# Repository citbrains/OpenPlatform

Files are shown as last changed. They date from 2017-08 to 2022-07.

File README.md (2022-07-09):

# OpenPlatform
Open Platform Humanoid Robot  

We are developing an open platform humanoid robot for the RoboCup Humanoid League.  
We aim to develop a robust robot system that helps the experiment on the real robot.  
The original robot was designed by Shimoyoshi.



GankenKun ver.3 (2020/11/22)



### Prizes
2019 RoboCup 4on4 3rd, Technical Challenge 2nd, Drop In Challenge 2nd  
2018 RoboCup 4on4 3rd, Technical Challenge 1st  
2017 RoboCup 4on4 3rd, Technical Challenge 1st  

### VIDEO
https://www.youtube.com/playlist?list=PLB7_jZwkBJdQZTIP_5HFZ_qUzT54mZ3Gq

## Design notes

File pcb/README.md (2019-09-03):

# PCB data

We design the circuit using EAGLE.

## Version 1

`ver1/OP_Robot_garv`: This circuit is the doughterboard for Raspberry Pi.  
For preview, see `OPR_Main_v2_board.pdf` and `OPR_Main_v2_schematics.pdf`.  

## Version 3

`ver3/power_circuit`: This circuit is the power supply switching circuit.  

## Bugs

If you find a bug please let me know by opening an issue.

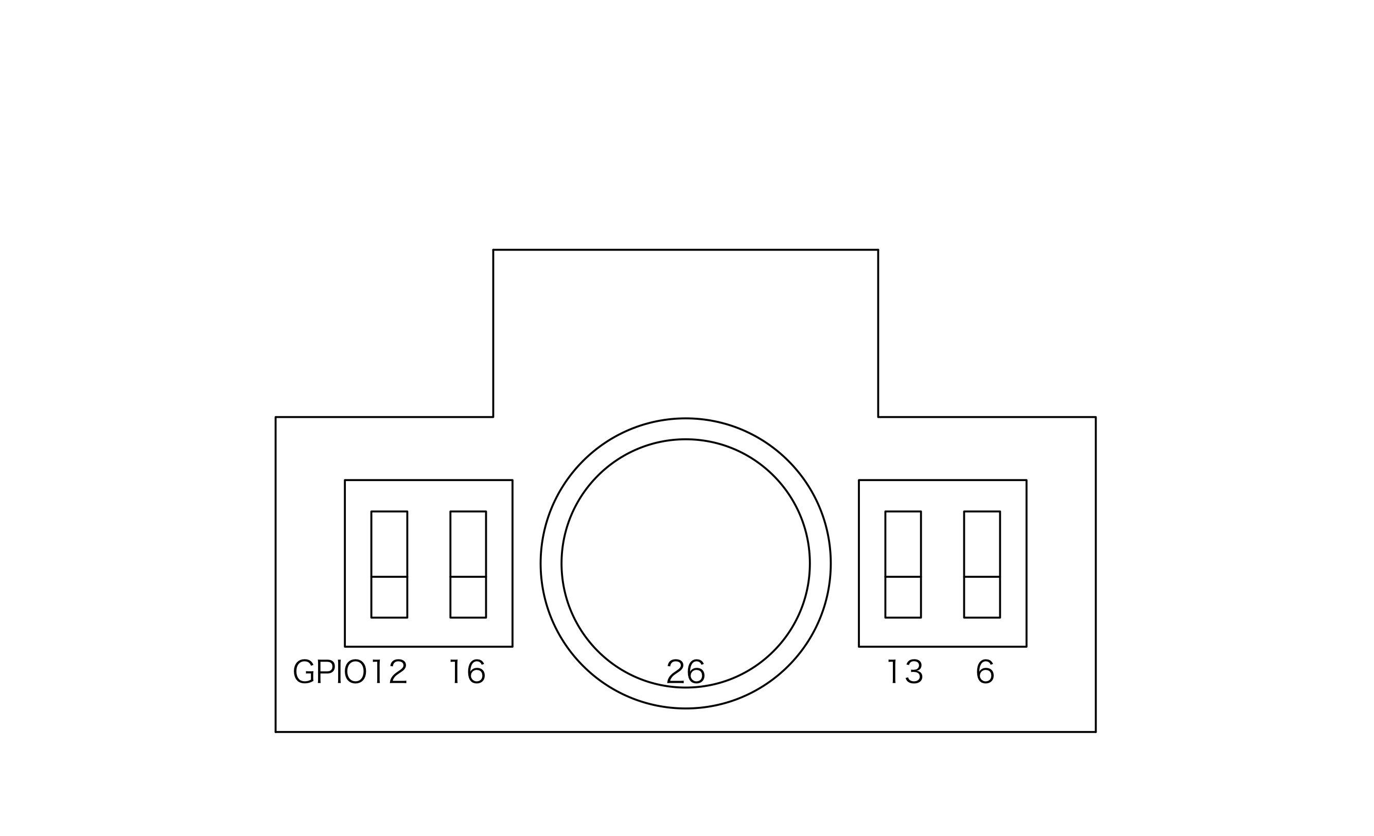
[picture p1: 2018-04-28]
mechanism/OPR_SW_assain.png

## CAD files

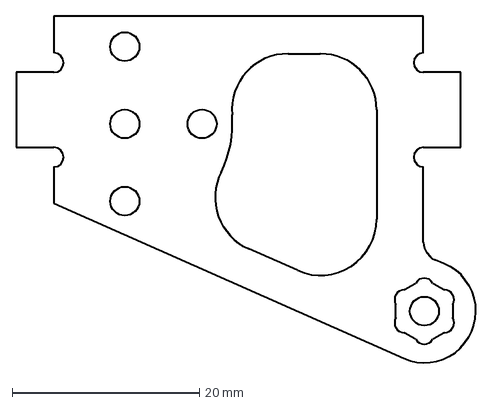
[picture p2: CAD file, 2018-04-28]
mechanism/OpenPlatform_ver3_0/dxf/A2017/2mm/付け根_サブフレーム_6_1.dxf
49.3 x 37.3 mm

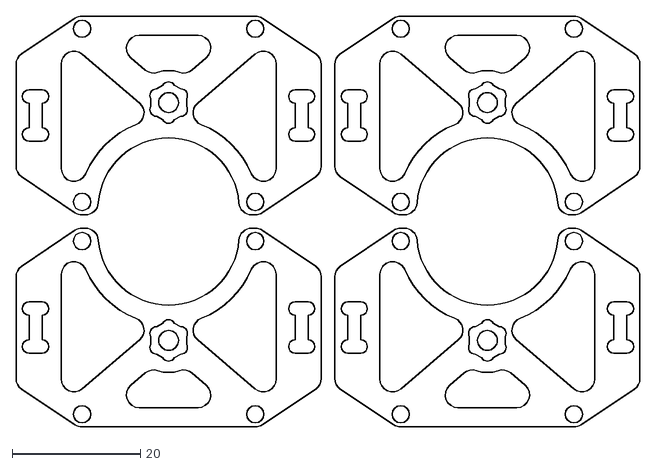
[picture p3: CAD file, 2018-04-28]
mechanism/OpenPlatform_ver3_0/dxf/A2017/3mm/付け根_メインフレーム_6_1.dxf
97.3 x 64.1

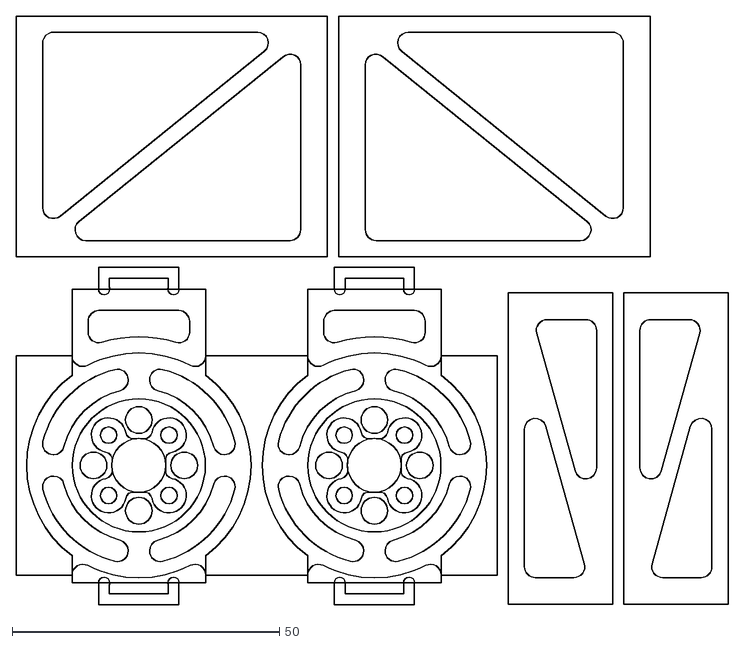
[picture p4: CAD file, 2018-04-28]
mechanism/OpenPlatform_ver3_0/dxf/A2017/5mm/付け根ロール_メインフレーム_6_1.dxf
133.3 x 110.2

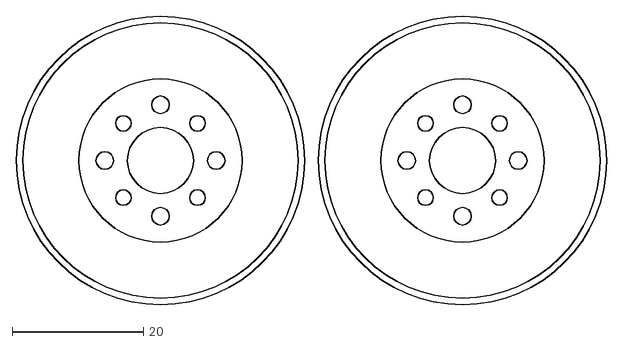
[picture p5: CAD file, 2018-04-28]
mechanism/OpenPlatform_ver3_0/dxf/A2017/付け根ロール_サブフレーム_6_4.dxf
90.1 x 44.0

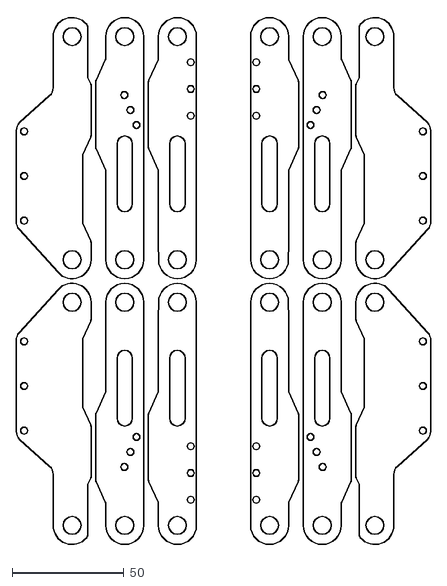
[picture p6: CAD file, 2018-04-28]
mechanism/OpenPlatform_ver3_0/dxf/GFRP/2mm/長穴減速_ホーン_1_2.dxf
185.7 x 237.5

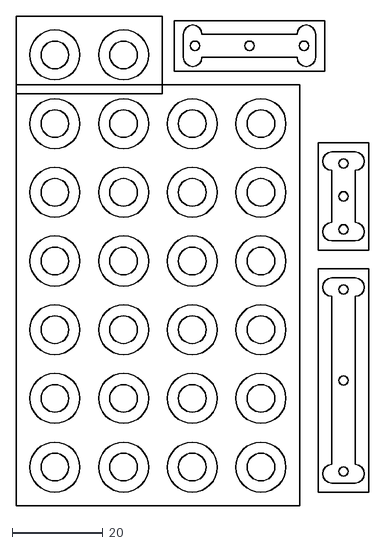
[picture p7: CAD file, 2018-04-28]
mechanism/OpenPlatform_ver3_0/dxf/POM/8mm/スペーサ.dxf
77.5 x 107.6

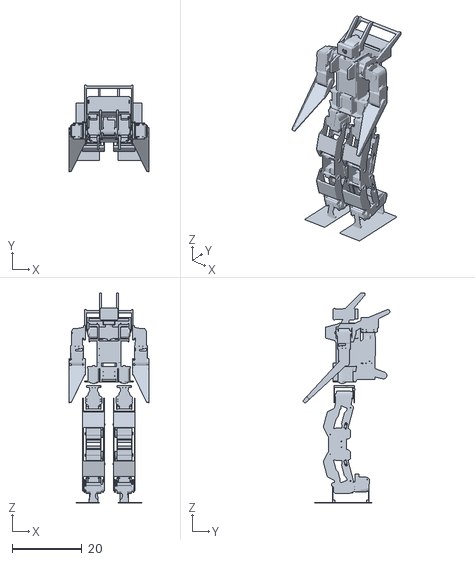
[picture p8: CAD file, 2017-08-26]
vrep/OpenPlatform_ver1_0_Sim.stl
23.0 x 24.9 x 60.2

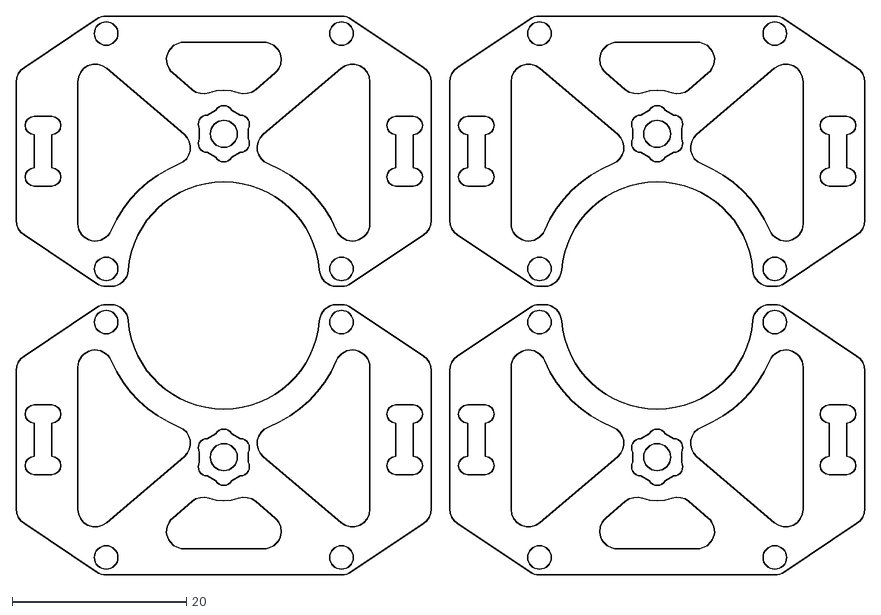
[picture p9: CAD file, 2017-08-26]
vrep/OpenPlatform_ver1_0_Sim/dxf/A2017/3mm/付け根_メインフレーム_6_1.dxf
97.3 x 64.1

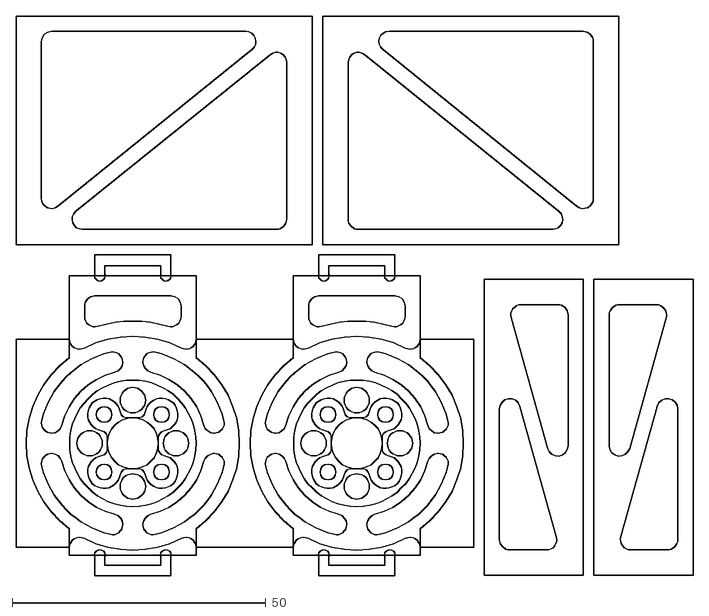
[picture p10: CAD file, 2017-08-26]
vrep/OpenPlatform_ver1_0_Sim/dxf/A2017/5mm/付け根ロール_メインフレーム_6_1.dxf
133.3 x 110.2

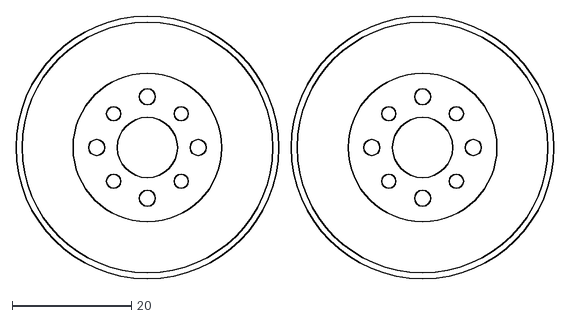
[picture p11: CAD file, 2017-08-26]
vrep/OpenPlatform_ver1_0_Sim/dxf/A2017/付け根ロール_サブフレーム_6_4.dxf
90.1 x 44.0

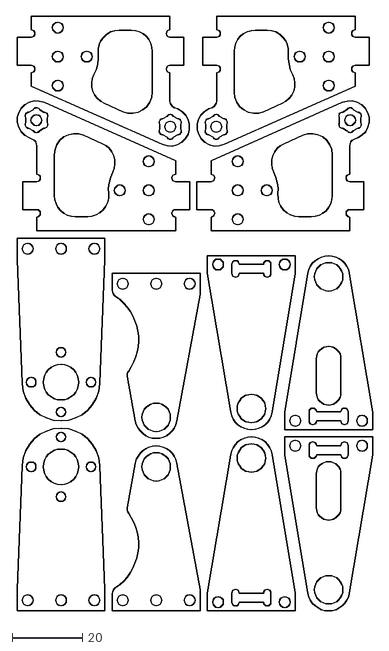
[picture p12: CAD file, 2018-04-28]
mechanism/OpenPlatform_ver3_0/dxf/A2017/2mm/足裏_メインフレーム_1_1.dxf
101.4 x 169.3

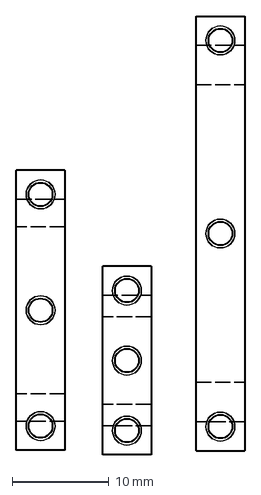
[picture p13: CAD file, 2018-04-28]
mechanism/OpenPlatform_ver3_0/dxf/POM/8mm/リンク_ふくらはぎ_サブフレーム_1_2(予備案).dxf
23.6 x 45.4 mm

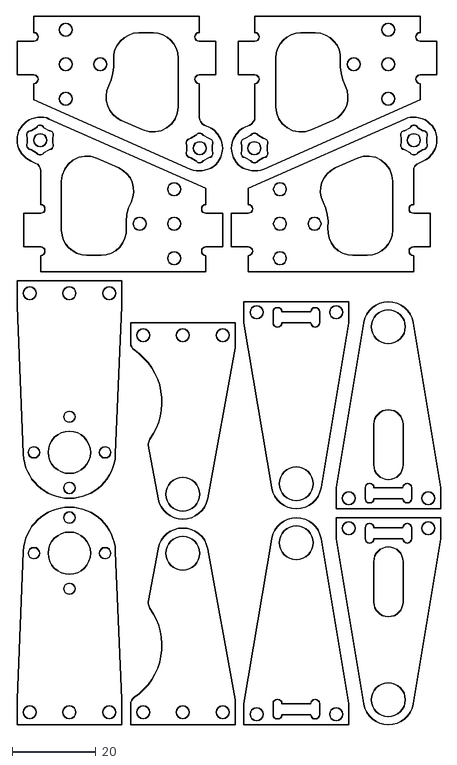
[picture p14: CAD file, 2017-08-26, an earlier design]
vrep/OpenPlatform_ver1_0_Sim/dxf/A2017/2mm/足裏_メインフレーム_1_1.dxf
101.4 x 169.3

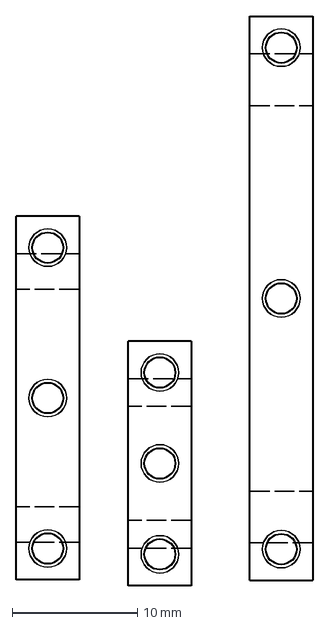
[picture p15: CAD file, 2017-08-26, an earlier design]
vrep/OpenPlatform_ver1_0_Sim/dxf/POM/8mm/リンク_ふくらはぎ_サブフレーム_1_2(予備案).dxf
23.6 x 45.4 mm

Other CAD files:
mechanism/OpenPlatform_ver3_0/dxf/GFRP/2mm/長穴減速_ホーン_1_2(1).dxf
vrep/OpenPlatform_ver1_0_Sim/dxf/POM/8mm/スペーサ.dxf
mechanism/OpenPlatform_ver1_0/上半身.iam
mechanism/OpenPlatform_ver1_0/上半身/コックピット/コックピット_2/コックピット_2.iam
mechanism/OpenPlatform_ver1_0/上半身/コックピット/コックピット_2/コックピット_2_サブフレーム_1.ipt
mechanism/OpenPlatform_ver1_0/上半身/コックピット/コックピット_2/コックピット_2_サブフレーム_2.ipt
mechanism/OpenPlatform_ver1_0/上半身/コックピット/コックピット_2/コックピット_2_サブフレーム_3.ipt
mechanism/OpenPlatform_ver1_0/上半身/コックピット/コックピット_2/コックピット_2_サブフレーム_4.ipt
mechanism/OpenPlatform_ver1_0/上半身/コックピット/コックピット_2/コックピット_2_サブフレーム_5.ipt
mechanism/OpenPlatform_ver1_0/上半身/コックピット/コックピット_2/コックピット_2_サブフレーム_6.ipt
mechanism/OpenPlatform_ver1_0/上半身/コックピット/コックピット_2/コックピット_2_メインフレーム_1.ipt
mechanism/OpenPlatform_ver1_0/上半身/コックピット/コックピット_2/コックピット_2_メインフレーム_1_MIR.ipt
mechanism/OpenPlatform_ver1_0/上半身/コックピット/コックピット_2/コックピット_2_メインフレーム_2.ipt
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

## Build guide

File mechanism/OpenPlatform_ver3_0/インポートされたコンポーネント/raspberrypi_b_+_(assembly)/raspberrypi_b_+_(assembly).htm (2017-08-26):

Autodesk Inventor 変換レポート | 2016年5月3日 ( 18:08)

ソース ファイル: | C:\Users\hiroaki\Documents\kenkyuu\二足\二足ver3.0\既製品\raspberry-pi-model-b-2.snapshot.15\raspberrypi_b_+_(assembly).SLDASM
トランスレータのタイプ: | SolidWorks | 送信システム: | SolidWorks 2013
作成者: | | 変換時間: | 00:00:23

オプション
インポートのタイプ: | N/A
インポートするエンティティ タイプ: | ソリッド, サーフェス, ワイヤ
修復環境に読み込む: | はい
アセンブリを単一パーツとしてインポート: | いいえ
次のサーフェスを作成: | 単一コンポジット フィーチャ
単位: | ミリメートル
ロード時にパーツを確認: | いいえ
自動ステッチ: | いいえ
高度なヒーリングを有効化: | N/A

## コンポーネント

次の表は、Inventor 内に作成されたパーツとアセンブリの一覧です:

+/- | 名前 | Inventor ファイル | ステータス
[ ] | raspberrypi_b_+_(assembly).iam | C:\Users\hiroaki\Documents\kenkyuu\二足\インポートされたコンポーネント\raspberrypi_b_+_(assembly)\raspberrypi_b_+_(assembly).iam | 成功
[ ] | raspberry_pi_B+_(bar_180_2x20).ipt | C:\Users\hiroaki\Documents\kenkyuu\二足\インポートされたコンポーネント\raspberrypi_b_+_(assembly)\raspberry_pi_B+_(bar_180_2x20).ipt | 成功
[ ] | raspberry_pi_B+_(QFN64).ipt | C:\Users\hiroaki\Documents\kenkyuu\二足\インポートされたコンポーネント\raspberrypi_b_+_(assembly)\raspberry_pi_B+_(QFN64).ipt | 成功
[+] [-] | raspberry_pi_B+_(168_FBGA_12x12).ipt | C:\Users\hiroaki\Documents\kenkyuu\二足\インポートされたコンポーネント\raspberrypi_b_+_(assembly)\raspberry_pi_B+_(168_FBGA_12x12).ipt | Warning

厳密度 | エンティティ ID | メッセージ
Warning | 25905 | 一部のサーフェスが簡略化されました
[ ] | raspberry_pi_B+_(micro_USB).iam | C:\Users\hiroaki\Documents\kenkyuu\二足\インポートされたコンポーネント\raspberrypi_b_+_(assembly)\raspberry_pi_B+_(micro_USB).iam | 成功
[ ] | raspberry_pi_B+_(micro_USB_cover).ipt | C:\Users\hiroaki\Documents\kenkyuu\二足\インポートされたコンポーネント\raspberrypi_b_+_(assembly)\raspberry_pi_B+_(micro_USB_cover).ipt | 成功
[ ] | raspberry_pi_B+_(micro_USB_contacts).ipt | C:\Users\hiroaki\Documents\kenkyuu\二足\インポートされたコンポーネント\raspberrypi_b_+_(assembly)\raspberry_pi_B+_(micro_USB_contacts).ipt | 成功
[ ] | raspberry_pi_B+_(HDMI_socket).iam | C:\Users\hiroaki\Documents\kenkyuu\二足\インポートされたコンポーネント\raspberrypi_b_+_(assembly)\raspberry_pi_B+_(HDMI_socket).iam | 成功
[ ] | raspberry_pi__HDMI_socket_cover.ipt | C:\Users\hiroaki\Documents\kenkyuu\二足\インポートされたコンポーネント\raspberrypi_b_+_(assembly)\raspberry_pi__HDMI_socket_cover.ipt | 成功
[ ] | raspberry_pi__HDMI_socket_inside.ipt | C:\Users\hiroaki\Documents\kenkyuu\二足\インポートされたコンポーネント\raspberrypi_b_+_(assembly)\raspberry_pi__HDMI_socket_inside.ipt | 成功
[ ] | raspberry_pi__HDMI_socket_large_pin.ipt | C:\Users\hiroaki\Documents\kenkyuu\二足\インポートされたコンポーネント\raspberrypi_b_+_(assembly)\raspberry_pi__HDMI_socket_large_pin.ipt | 成功
[ ] | raspberry_pi__HDMI_socket_small_pin.ipt | C:\Users\hiroaki\Documents\kenkyuu\二足\インポートされたコンポーネント\raspberrypi_b_+_(assembly)\raspberry_pi__HDMI_socket_small_pin.ipt | 成功
[+] [-] | raspberry_pi_B+_(RJ45).ipt | C:\Users\hiroaki\Documents\kenkyuu\二足\インポートされたコンポーネント\raspberrypi_b_+_(assembly)\raspberry_pi_B+_(RJ45).ipt | Warning

厳密度 | エンティティ ID | メッセージ
Warning | 114479 | 一部のサーフェスが簡略化されました
[ ] | raspberry_pi_B+_(15_pin_FFC_Connector).iam | C:\Users\hiroaki\Documents\kenkyuu\二足\インポートされたコンポーネント\raspberrypi_b_+_(assembly)\raspberry_pi_B+_(15_pin_FFC_Connector).iam | 成功
[ ] | raspberry_pi__15_pin_FFC_Connector_body.ipt | C:\Users\hiroaki\Documents\kenkyuu\二足\インポートされたコンポーネント\raspberrypi_b_+_(assembly)\raspberry_pi__15_pin_FFC_Connector_body.ipt | 成功
[ ] | raspberry_pi__15_pin_FFC_Connector_locker.ipt | C:\Users\hiroaki\Documents\kenkyuu\二足\インポートされたコンポーネント\raspberrypi_b_+_(assembly)\raspberry_pi__15_pin_FFC_Connector_locker.ipt | 成功
[ ] | raspberry_pi__15_pin_FFC_Connector_pins.ipt | C:\Users\hiroaki\Documents\kenkyuu\二足\インポートされたコンポーネント\raspberrypi_b_+_(assembly)\raspberry_pi__15_pin_FFC_Connector_pins.ipt | 成功
[ ] | raspberry_pi_B+_(CI_Board).ipt | C:\Users\hiroaki\Documents\kenkyuu\二足\インポートされたコンポーネント\raspberrypi_b_+_(assembly)\raspberry_pi_B+_(CI_Board).ipt | 成功
[ ] | raspberry_pi_B+_(USB_x2).iam | C:\Users\hiroaki\Documents\kenkyuu\二足\インポートされたコンポーネント\raspberrypi_b_+_(assembly)\raspberry_pi_B+_(USB_x2).iam | 成功
[+] [-] | raspberry_pi_B+_(USB_x2_part1).ipt | C:\Users\hiroaki\Documents\kenkyuu\二足\インポートされたコンポーネント\raspberrypi_b_+_(assembly)\raspberry_pi_B+_(USB_x2_part1).ipt | Warning

厳密度 | エンティティ ID | メッセージ
Warning | 53294 | 一部のサーフェスが簡略化されました
Warning | 47846 | 一部のサーフェスが簡略化されました
[+] [-] | raspberry_pi_B+_(USB_x2_part2).ipt | C:\Users\hiroaki\Documents\kenkyuu\二足\インポートされたコンポーネント\raspberrypi_b_+_(assembly)\raspberry_pi_B+_(USB_x2_part2).ipt | Warning

厳密度 | エンティティ ID | メッセージ
Warning | 55606 | 一部のサーフェスが簡略化されました
[+] [-] | raspberry_pi_B+_(microsd_slot2).ipt | C:\Users\hiroaki\Documents\kenkyuu\二足\インポートされたコンポーネント\raspberrypi_b_+_(assembly)\raspberry_pi_B+_(microsd_slot2).ipt | Warning

厳密度 | エンティティ ID | メッセージ
Warning | 134524 | 一部のサーフェスが簡略化されました
[+] [-] | raspberry_pi_B+_(microsd2).ipt | C:\Users\hiroaki\Documents\kenkyuu\二足\インポートされたコンポーネント\raspberrypi_b_+_(assembly)\raspberry_pi_B+_(microsd2).ipt | Warning

厳密度 | エンティティ ID | メッセージ
Warning | 154052 | 一部のサーフェスが簡略化されました
[ ] | raspberry_pi_B+_(audio_video2).ipt | C:\Users\hiroaki\Documents\kenkyuu\二足\インポートされたコンポーネント\raspberrypi_b_+_(assembly)\raspberry_pi_B+_(audio_video2).ipt | 成功

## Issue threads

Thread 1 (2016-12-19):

GPIOの設定を変えると最新版のRasbianでカーネルパニックが起きる

yoshiya01, 2016-12-19:
最新のRasbian
Version:November 2016
Release date:2016-11-25
Kernel version:4.4
において
GPIOのシリアルをmini-uartから切り替える操作を行うとカーネルパニックを起こす事が分かっています

以下が操作内容になります
1./boot/config.txtを編集する
末尾にこの行を追記
`dtoverlay=pi3-miniuart-bt`

2./boot/cmdline.txtを編集する
#内容を書き換え
`dwc_otg.lpm_enable=0 console=tty1 console=serial0,115200 root=/dev/mmcblk0p2 rootfstype=ext4 elevator=deadline fsck.repair`

yoshiya01, 2016-12-19:
wikiの方に移すのでcloseします

Closed 2016-12-19.

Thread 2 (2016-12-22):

Raspberry Pi3とカメラモジュールを接続するフレキシブルなケーブルを探す

yasuohayashibara, 2016-12-22:
Raspberry Pi3とカメラモジュールを接続するフレキシブルなケーブルを探して購入する．
ロボカップの頭部にカメラモジュールを取り付けてリアルタイムに画像を取得する場合，USBよりCSIの方が問題が少ないと感じるが，フィルムケーブルでは取り回しや断線が問題となる．
フレキシブルで屈曲に強いCSI用のケーブルを探す．

yasuohayashibara, 2016-12-22:
規格は以下であると思われます．
15ピンMIPIカメラシリアルインターフェイス(CSI)
https://www.switch-science.com/catalog/2714/

yasuohayashibara, 2016-12-22:
MIPI: Mobile Industry Processor Interface
モバイル機器のカメラやディスプレイとのインターフェイス規格
CSI-2: Camera Serial Interface
カメラ用のデータ信号とクロック信号を持つ単方向の差動シリアルインターフェース

http://www.cypress.com/file/127366/download
http://jp.tek.com/dl/F1_TIF2012_MIPI.pdf

ケーブルとしての規格はない？

yasuohayashibara, 2016-12-22:
延長ケーブルはありそう
https://www.adafruit.com/product/1648

ロボットに使用している例もあるが，果たして耐久性はどうなのか
https://www.gadgetdaily.xyz/10-ways-to-make-php-beautiful/

yasuohayashibara, 2016-12-22:
KELという会社に問合せを送りました．
http://www.kel.jp/
-

林原 靖男　様

■製品情報お問い合わせフォームより自動送付されたメールです。■
この度はお問い合わせいただき、誠にありがとうございました。
お問い合わせいただきました内容を確認の上、
後ほど担当よりご連絡させていただきます。

■お問い合わせ事項
お問い合わせカテゴリ：お見積もり
お問い合わせ製品・品種：ケーブル
お問い合わせ内容  ：Raspberry Pi3で使用できるカメラケーブルを探しています．
15ピンMIPIカメラシリアルインターフェイス(CSI)
https://www.switch-science.com/catalog/2714/

ロボットに使用しますが，一般的に販売されているケーブルでは取り回しがしにくいのと，屈曲を頻繁に繰り返しますので断線が心配されます．

御社は上記のような条件でのCSIのケーブルの製作で実績があるとお聞きしておりますので，申し訳ありませんが条件に合致する40cm程度のケーブルをご提案いただければと思います．

なお，来年の７月にロボカップというイベントがあり，それに向けた開発で少々急いでおります．

お手数をおかけしますが，どうぞよろしくお願いいたします．

yasuohayashibara, 2016-12-28:
KELからの回答です．

お問い合わせの件
弊社製品にて、ご案内できる物としては細線同軸ハーネス品になるかと思われます。
用途として最適かどうか不明ですが、細線同軸ケーブルは念回特性に於いては、通常の
ディスクリートケーブルより良いと思われます。
弊社細線同軸ハーネスは、監視カメラ、カムコーダー等、画像関連の機器に採用されております。

カタログをお送りしますので、参照頂ければと思います。
入手については、ご相談を承りたくお願いいたします。
（基板側はエンボスリールのＭＯＱが500個で大きいため）
宜しくお願いいたします。

[ＵＳＬＳカタログ.pdf](https://github.com/citbrains/OpenPlatform/files/675324/default.pdf)
[ＵＳＬカタログ.pdf](https://github.com/citbrains/OpenPlatform/files/675323/default.pdf)
[SSLカタログ.pdf](https://github.com/citbrains/OpenPlatform/files/675322/SSL.pdf)

yasuohayashibara, 2016-12-28:
Raspberry PI 3のカメラコネクタ(CSI-2)についてもう少し調べた．

1mm 15pのFFC(Flexible Film Cable)かFPC(Flexible Printed Circuit)

ZIF 15 socket
The Raspberry Pi CSI connector is a surface mount ZIF 15 socket, used for interfacing a camera through a ribbon cable

http://www.petervis.com/Raspberry_PI/Raspberry_Pi_CSI/Raspberry_Pi_CSI-2_Connector_Specifications.html

yasuohayashibara, 2017-01-12:
他の候補は無さそうなので，AMAZONの長いケーブルを購入してそれを使用する．
閉じます．

yasuohayashibara, 2019-11-22:
こちらで同軸ケーブルを見つけた．
https://www.e-consystems.com/jp/13mp-autofocus-nvidia-jetson-tx2-camera-board-jp.asp

Closed 2017-01-12.

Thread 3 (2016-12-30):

Raspberry PIの情報

yasuohayashibara, 2016-12-30:
161230におけるRaspberry PI関連の情報
IP Address 192.168.2.2
メモリ 16G

imu動作　 mpu-6050.py
servo動作　servo_test.py
18pinをRS485の切替に使用している．
首のパン(19番)のサーボだけ119200bps

rasbian 最新版は使用しない
bluetoothも使用しない（最新版では動かない）
NG　シリアルのピンをGPIOで使用しない．

tightvncserverと入力するとVNCが使用できる
ポート：5901

yasuohayashibara, 2016-12-30:
共有する目的を達したので閉じます．

Closed 2016-12-30.

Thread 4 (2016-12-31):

ARMでのロボカップソースコードのコンパイル

yasuohayashibara, 2016-12-31:
@yotaseki @ChisatoKasebayashi
Raspberry PIでロボカップのソースコードをビルドしていますが，hr42はすんなりとビルドできたのですが，認識ライブラリの方は以下のエラーが発生しています．
Raspberry PIでRaspbianを使用しているという違いはありますが，Jestonと近い環境だと思いますので，心あたりがありましたら教えてください．

ちなみに，Ubuntuと同様のセットアップをしています．

```
cit@raspberrypi:~/citbrains_humanoid/for2050/src $ make
[  1%] Building CXX object HCServer/CMakeFiles/HCLib.dir/__/gen/StringSender.o
*** Error in `/usr/bin/c++': double free or corruption (top): 0x00f27398 ***
Aborted
HCServer/CMakeFiles/HCLib.dir/build.make:69: recipe for target 'HCServer/CMakeFiles/HCLib.dir/__/gen/StringSender.o' failed
make[2]: *** [HCServer/CMakeFiles/HCLib.dir/__/gen/StringSender.o] Error 134
CMakeFiles/Makefile2:93: recipe for target 'HCServer/CMakeFiles/HCLib.dir/all' failed
make[1]: *** [HCServer/CMakeFiles/HCLib.dir/all] Error 2
Makefile:127: recipe for target 'all' failed
make: *** [all] Error 2
```

yotaseki, 2017-01-01:
CMakeList.txtに書かれている以下の行が原因です
```c
SET (CMAKE_CXX_FLAGS "-march=native")
```
私も詳しく把握しているわけではありませんが,ARMの場合はこの最適化オプションは使用できないみたいです.

yasuohayashibara, 2017-01-02:
@yotaseki ありがとう．ビルドできるところまで確認しました．

yasuohayashibara, 2017-01-02:
解決したので閉じます．

yasuohayashibara, 2017-01-03:
Raspberry Pi camera 2.1で画像処理部の動作確認ができた．
解像度はまだ640x480であるが，快適に動作している．
https://youtu.be/2m3d11I4ybo

Closed 2017-01-02.

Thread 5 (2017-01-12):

無線LANがつながらない

yasuohayashibara, 2017-01-12:
WIKIに書いた設定を行っても無線LANが接続されない．
sudo iwlist wlan0 scan
ではアドレスが表示されるが，GUIで接続しようとしても接続できない．
手順を再度確認する．

ryuichiueda, 2017-01-12:
ラズパイ3でしょうか？Wikiまで追っかけられないんですけど、ラズパイの場合だと色々気をつけることがあります。

yasuohayashibara, 2017-01-13:
ラズパイ３です．
networkmanagerを入れると無線LANに繋がりましたが，動きが全体に緩慢になったような気がします．
（気がするだけかもしれませんが．．．）
ちなみに，VNCで操作しています．
あとで相談させて下さい．

ryuichiueda, 2017-01-13:
承知しました。ここらへんはノウハウの塊です。

yasuohayashibara, 2017-01-14:
後でwikiにまとめようかと思いますが，繋がりました．
自宅がまだWEPでしたので，それも問題を複雑にしていたかもしれません．

-----
WIFIの設定
http://qiita.com/yosi-q/items/c677e4650b22ffffa806

WEPの設定
http://nlogn.ath.cx/archives/001378.html

interfacesに以下を追加
wireless-power off

-----
解決したので閉じます．

yasuohayashibara, 2017-01-14:
そういえばnetwork-managerをapt-get removeしたら動きが早くなりました．
Jessieにnetworkmanagerは相性が悪いようです．

Closed 2017-01-14.

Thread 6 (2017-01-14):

RaspiberryPiのUARTのボーレートを上げる方法

yoshiya01, 2017-01-14:
藤田くん調査頼みました。(急がなくていいです)
現状クロックに影響されている？みたい
現状115200bpsであれば通信出来ますが、
1.5Mbpsでは出来てないのでこれを解決して下さい。
取り敢えず1.5Mbpsまで上げなくてもいいのでより高いボーレートで出来るようにしてみて下さい
(UARTのボーレートはいくつかパターンが有ります。)

バタバタしてて環境を整えきれてないので、
PCとRaspi間でのテストをお願いします。
これなら必要な物が少ないので。
必要なもの
UARTUSB変換(PC-Raspi間でテスト用)

ボーレートを上げられた様なら以下の物でテストして下さい。
メイン基板(RS485変換)
サーボ
サーボ書き換えツール(サーボ側のボーレートを書き換えるため)
電源

yasuohayashibara, 2017-01-14:
Raspi3ではないですが，すでにLinuxから1.5MBPSで通信できています．
手順をどこかに書いたような気がしますが，かなり特殊な処理をしないといけません．
（見つけたらこちらにリンク先を添付してくれると助かります．）

ソースコードはこちら
https://github.com/citbrains/citbrains_humanoid/pull/694

yasuohayashibara, 2017-01-24:
https://github.com/citbrains/citbrains_humanoid/commit/8126356cec6a4decc471b20caf04ec4b536c57a1
で対応しました．

以下，ラズベリーパイ＋自作回路から歩行パターンを再生している様子です．
https://youtu.be/Nf5K_VBkBDM

一つ注意事項として，
WiringPIを使用しましたが，従来のGPIO18がWiringPIだとGPIO1に割り当てられており，そこで時間を費やしてしまいました．今後使用する場合はお気をつけ下さい．

解決したので閉じます．

Closed 2017-01-24.

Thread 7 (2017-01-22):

v3基板改良点

yoshiya01, 2017-01-22:
ダイオード追加
Accelit_SWにLED(RS485切り替え部分のステータス表示)

yasuohayashibara, 2017-01-23:
「RS485切り替え部分のステータス表示」はあった方が良いですが，優先順位は低いです．
次の基板で欲しいのは，以下の機能です．
（外付けの基板でも構いません）

１）ステータスを表示するLED　(できれば4つぐらい)
２）音声出力（うるさい環境で使用するため出力大きめ）
３）音声入力

以上，ご検討下さい．

yasuohayashibara, 2017-01-25:
「リアルタイムクロック」も追加した方が良いです．

１）ステータスを表示するLED　(できれば4つぐらい)
２）音声出力（うるさい環境で使用するため出力大きめ）
３）音声入力
４）リアルタイムクロック

yasuohayashibara, 2018-10-27:
改良した基板
動作確認後にmasterに反映します．

[181026部品.xlsx](https://github.com/citbrains/OpenPlatform/files/2521271/181026.xlsx)
[101826_open_platfom.zip](https://github.com/citbrains/OpenPlatform/files/2521272/101826_open_platfom.zip)

yasuohayashibara, 2018-10-31:
動作確認のため製作して電源投入した．
まだ電源のみの確認

パターンにミスがあった（赤線）とはんだ付け時にパターンを損傷（黒色）してジャンパーピンをつけた．
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

電源は問題なく動作
https://youtu.be/yW3xjvKYTS4

以下，問題
１）0.1uFのコンデンサのはんだ付けが困難なため変更
２）抵抗が必要以上に小さいと思われるので，もう少し大きなものに変更したほうが良い．
３）ファンを固定するネジを長くする．今はM2.6x10

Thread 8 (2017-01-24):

カメラの画像を180度回転させる

yasuohayashibara, 2017-01-24:
カメラの設置が上下逆になるため，画像を180度回転させる．

yasuohayashibara, 2017-01-24:
/etc/rc.localのexit 0の前に以下を追加

```
v4l2-ctl --set-ctrl horizontal_flip=1
v4l2-ctl --set-ctrl vertical_flip=1
```

その他オートホワイトバランスなどの設定も同じようにv4l2-ctlでできそう．

Closed 2017-01-24.

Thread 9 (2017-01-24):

画像処理の速度の調査

yasuohayashibara, 2017-01-24:
画像処理の速度を調査する．
Acceliteが現在10FPSであるため，まずはその速度を目指す．

yasuohayashibara, 2017-01-24:
解像度が低いと思われるので，単純には比較できないが，一通り動作している状態で0.03s程度であった．
この条件であれば，20FPSも可能かもしれない．

Raspberry PI3
https://youtu.be/Dl8cN0mzyf4

Accelite (参考まで)
https://www.youtube.com/watch?v=kHBadCs3Mnk
※しばしば負荷が高まるのは，深層学習が動いたため？

Raspberry PI3はhr42のプロセスを起動せずに実験したが，そちらの待ち時間が長くなっている．全体のパフォーマンスに関わることかもしれないので，後で調査したほうが良い．

Closed 2017-01-24.

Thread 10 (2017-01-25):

IMUのサンプルプログラム

yasuohayashibara, 2017-01-25:
IMUの動作確認のため，サンプルプログラムを作成する．
@yoshiya01 pythonでも構いませんので，もしあったらアップして下さい．

yoshiya01, 2017-01-27:
アップしておきましたmpu-6050.pyです

yasuohayashibara, 2017-01-28:
動作確認できました．

こちらにあったサンプルも動かしましたが，嫌になるぐらい簡単ですね．
https://www.raspberrypi.org/forums/viewtopic.php?t=22266
とりあえず，こちらのライブラリをそのまま使用したいと思います．

１人で撮影したのと線が細いので良くわからないところもありますが，操作している感覚としては完全に同期しています．
https://youtu.be/0QjVnoqxedI

※ここまで30分．．．

閉じます．

yasuohayashibara, 2017-01-29:
前回アップした動画がわかりにくかったので取り直しました．
https://youtu.be/DtIKNvIApEQ

ネットが安定していなくて少し停止しているところもあります．

Closed 2017-01-28.

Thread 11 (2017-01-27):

歩行プログラムを実行しても歩行パターンが再生されない

yasuohayashibara, 2017-01-27:
以下のコマンドで歩行プログラムを実行しても，歩行パターンが再生されない．

sudo ./hr42_win

yasuohayashibara, 2017-01-27:
以下で再生できることを確認

sudo su
./hr42_win

おそらくファイルの権限が書き換わり，それにより再生できなくなったのだと思われます．
エラーが表示されないので分からないのですが，通信関係のデバイスの権限が問題かなと予測しています．

問題が発生した経緯と対処は以下の通り．

林原のPCから，
sudo ./hr42_win　で再生可

IPアドレスを変更．林君のPC(MAC)から
sudo ./hr42_win　で再生不可　←　ここで権限が書き換わる？

IPアドレスを戻す．林原のPCから，
sudo ./hr42_win　で再生不可

林原のPCから，
sudo su
./hr42_win
で再生可

もう少し調査して，
sudo ./hr42_win　で再生可になったら閉じます．

yasuohayashibara, 2017-01-28:
以下で解決したが，それまでの手順を示す．
https://github.com/citbrains/citbrains_humanoid/commit/dfead004b1664990874900d59f0cdba3e9407980

メモ書き程度

１）予めGPIO18(RS485の方向を決めるGPIO)をOUTPUT,HIGHにしてみたが変化なし

２）サンプル(sero_test.py)がGPIO18で送信モードにしてからポートをオープンしているのでそちらに変更
→　変わらず

３）pythonでシリアルをOpen,Closeだけする．
→　動作　→　Pythonでオープンした時の設定が引き継がれている．

４）どのようにシリアルの設定が書き換わったかをチェック
sudo stty -F /dev/ttyAMA0でチェック

・Raspberry PI 3起動時
speed 9600 baud; line = 0;
-brkint -imaxbel

・hr42を起動（通信できない）
AMA0
speed 1500000 baud; line = 0;
-brkint -imaxbel

・servo_test.pyを起動（通信できる）
speed 115200 baud; line = 0;
min = 0; time = 0;
-brkint -icrnl -imaxbel
-opost
-isig -icanon -iexten -echo -echoe -echok -echoctl -echoke

再度hr42を起動（通信できる）
AMA0
speed 1500000 baud; line = 0;
min = 0; time = 0;
-brkint -icrnl -imaxbel
-opost
-isig -icanon -iexten -echo -echoe -echok -echoctl -echoke

これらからより詳細にポートを設定することで，通信できるようになる．KONDOのアダプタを介して通信する場合は，おそらくこれらの設定をH/Wで吸収しているので問題なかったと思われる．

解決したので閉じます．

Closed 2017-01-28.

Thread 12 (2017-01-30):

自立化

yasuohayashibara, 2017-01-30:
ロボット内にバッテリや処理系など自立的に動くための仕組みを全て入れる．

yasuohayashibara, 2017-01-30:
全て入れた．

以下，自立的に歩行する動画
https://youtu.be/3y0U-XKdfN4

頑健さを検証する必要はあるが，とりあえず必要なH/Wが揃ったことを確認した．
閉じます．

yasuohayashibara, 2017-02-03:
開発中のためトルクに制限をかけていたのを忘れていました．
前のビデオは３割のトルクで歩いています．

Closed 2017-01-30.

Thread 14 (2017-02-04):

ジャイロフィードバックを歩行に組み込む

yasuohayashibara, 2017-02-04:
ジャイロフィードバックを歩行に組み込んで振動を抑制する

yasuohayashibara, 2017-02-04:
組み込んで動作確認を行った．

ジャイロに反応して動く様子
https://youtu.be/5eo-IoxVj8w

ジャイロの効果（それほど調整していませんが効果は分かります．）
前半：ジャイロあり，後半：ジャイロなし
https://youtu.be/-lpHDA9pC3E

MPU6050は安定しており，応答も早いと感じました．

ただし，起動後20秒ぐらいはキャリブレーションのため動かすことができません．
（そのうち改善します）

閉じます．

Closed 2017-02-04.

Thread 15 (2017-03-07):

ハードウェア製作

yasuohayashibara, 2017-03-07:
CADデータに従ってハードウェアを製作する．
オリジナルマインドのCNCを使用する．
製作時の様子をWIKIに記すことで，製作に関するハードルを下げる．

yasuohayashibara, 2017-03-07:
CUT2Dでツールパスを作り，USBCNCで軌道に沿ってエンドミルと制御している様子
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

加工の様子
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

上記と別の部品ですが加工の様子
https://youtu.be/9dqzLQ03Xsw

yasuohayashibara, 2017-03-08:
加工したものを表示しないようにすると，現在こんな感じ．
A2017の5mmの最後の部品を削っています．
ツールパスの作り方もだいぶ慣れました．
プラモデルを作るみたいで楽しいですね．
ちなみに，右半分は比較のために残してあります．

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

yasuohayashibara, 2017-03-09:
ようやくGFRPの切削に取りかかる．
5mmのA2017は切削に2日間要したが，GFRPだとこれが１時間半程度で切削完了するとのこと．

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

https://youtu.be/MmNZpBxu-sg

yasuohayashibara, 2017-03-09:
切削開始６日の状況（消したものが加工済み）
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

加工した部品
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

粉の中から部品が出てくる様子（切削時間は１時間強．樹脂はさくさく削れます．）
https://youtu.be/cSRPZJ8UISM

yasuohayashibara, 2017-03-10:
A2017(3mm)は14時間かかるとのこと
本日分の加工分終了

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

yasuohayashibara, 2017-03-11:
ほぼ一週間後の様子．消したものが加工済み．
厚い金属を削る場合は切削時間が12時間を超えることもあるので，なかなか進まない．
とはいえ，ツールパスが予めできあがっていれば，初期位置だけ設定して削り出せばよいだけなので手間いらず．今日も確認して，実行までに15分程度要しただけです．
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

バリ取りと追加工は大変そうであるが，それは後回しにしてとりあえず部品の加工を進めています．

yasuohayashibara, 2017-03-14:
現在の状況です．
これでアルミA2017の3mm以上のものは全て終了です．
明日，明後日と学会の講演会なので，しばらくおやすみ．

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

腰と足首あたりの部品です．

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

yasuohayashibara, 2017-03-17:
ほぼ２週間後の様子
足回りと胴体の半分ぐらいは終わりました．
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
昼間だけ切削した場合は，１ヶ月ぐらいかかりそうです．
切削後のバリ取りにも時間が取られます．

本日取り外してバリ取りした材料
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
POMに移ったので少しペースが早くなりましたが，材料の厚さがまちまちで面出ししてから削っているので厚さの精度が出ているPOMの場合はもっと早いと思います．

yasuohayashibara, 2017-03-17:
本日加工の部品を組んでみた．
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

ピッタリはまります．ネジや接着剤は使用しません．
この中にコンピュータ(Raspberry-PI3)やセンサ類を入れます．
ロボットからこの部分だけ外してメンテナンスできるようになっています．

yasuohayashibara, 2017-04-18:
だいぶ内容が飛んでしまいましたが，下半身完成しました．
組み立てにはいくつかコツが必要で，

１）股ヨー軸は六角スペーサの角度が重要で，ある角度にしないと干渉します．
　　（説明が難しい．．．）
２）一部ネジの長さを調整しないと締め込めないところがあります．
　　（ナットが入ってどんつきのあるところ）

いずれドキュメント化しようと思いますが，ご注意下さい．

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
（干渉しているのか右股ヨー軸だけ動きが悪い．．．）

yasuohayashibara, 2017-04-19:
上半身も組み立てられるところは組み立てました．
いくつか作り忘れの部品がありますので，それを削り出してから次のステップへと進みます．

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

yasuohayashibara, 2017-04-23:
肩の部品に製造ミスが見つかったので，完成させられませんでしたが，あと少しの状態になりました．

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

yasuohayashibara, 2017-04-23:
実はヒューマノイドの板金の曲げ加工は初めてでしたが見事に失敗しました．
首が傾いています．
本OPに曲げ加工があまり無いというのは，特殊な技術が無くてもロボットを精度高く製作できるという観点で重要ですね．
作り直します．

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

yasuohayashibara, 2017-04-27:
最後の作り直し部品
![Uploading DSC_1766.JPG…]()
2個で切削8時間程度

yasuohayashibara, 2017-04-27:
メカニズムの主要な部分はほぼ完成
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

関節も滑らかに動いてガタツキもなく良い感じです．

yasuohayashibara, 2017-05-07:
配線して歩行のチェックをしました．
https://youtu.be/vMIzm2KI45c

回路製作と配線は学生がしてくれました．
いずれ林原も時間を見つけて行いたいと思います．

まだカメラを取り付けてないので，取り付けて動作確認したらこのissueは終了です．

yasuohayashibara, 2017-08-05:
カメラを取り付けて動作確認しました．
issueを閉じます．

Closed 2017-08-05.

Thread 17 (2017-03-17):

歩行パターンの再生に関する検討

yasuohayashibara, 2017-03-17:
歩行パターンがどの程度正確に再現されるかを検討する．

yasuohayashibara, 2017-03-17:
歩行させた時の上腿の角度の例
（最もトルクが要求される関節の一つ）

足上げ量20mmの場合　支持脚が切り替わるまでの時間　0.32s
歩行パターンから要求される最大角速度　138deg/s
計測されたパターンから計算された最大角速度　106deg/s
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
横軸は時間(s)

足上げ量50mmにすると下記のようにサーボモータの速度の上限の影響で目標軌道に追従できていない．
歩行パターンから要求される最大角速度　336deg/s
計測されたパターンから計算された最大角速度　129deg/s
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

サーボモータの仕様から最高角速度は142deg/sであるため，ほぼ仕様どおりの速度で飽和していることが分かる．
ただし，歩行の様子を見るかぎり関節の速度が遅いということはないため，この制限内で動かすように歩行パターンを調整した方が良いと考えられる．

ちなみに，外力が加わっても力負けすること無く予定通りの軌道を描くことができている．

yasuohayashibara, 2017-08-05:
再現されることが判明したのでissueを閉じます．

Closed 2017-08-05.

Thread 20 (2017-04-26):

Kondo RS485USB/シリアル変換アダプターを使用した通信

yasuohayashibara, 2017-04-26:
Kondo RS485USB/シリアル変換アダプターを使用した通信ができるようにする．

yasuohayashibara, 2017-04-26:
サーボの設定

/etc/udev/rules.d/ に保存
```
80-kondo-b3m.rules

# set permission to all Kondo device
ACTION=="add", SUBSYSTEM=="usb", ATTR{idVendor}=="165c", MODE="0666"
KERNEL=="ttyUSB*", MODE="0666", ATTRS{product}=="RS485 USB/Serial Converter", ATTRS{serial}=="KOUSB485"

-----

sudo su
modprobe ftdi-sio
echo 165C 0009 > /sys/bus/usb-serial/drivers/ftdi_sio/new_id
exit
```

1.5MBPSで通信するための方法は以下を参照

https://github.com/citbrains/kondo_driver

@RikiHayashi ご参照下さい．

yasuohayashibara, 2017-05-07:
記録に残しただけですので，閉じます．

Closed 2017-05-07.

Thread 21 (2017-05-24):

モーション再生時の問題

yasuohayashibara, 2017-05-24:
FutabaからKondoにするにあたり，モーション再生の仕組みを大きく変える必要がある．

モータのコマンドに関して以下の違いがある．
Futaba 角度と到達時間を指定
Kondo 角度のみ指定

つまり，Futabaは軌道を自動的に線形補間するが，Kondoはそれを行わないため，CPU側で線形補間して10ms周期で送信する必要がある．
少なくともMotionCreatorには線形補間する機能はないため，新たに実装することが必要．

Kondoも速度を指定する方法はあるが，どちらにしてもマイナーなアップデートで済む問題ではなさそうである．

yasuohayashibara, 2017-08-05:
問題は共有できたのでissueを閉じます．

Closed 2017-08-05.

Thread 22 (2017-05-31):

ジャパンオープンでの問題点

yoshiya01, 2017-05-31:
戦略が起動できなくなる
ネットワーク周りのファイルをマージしてコンパイルした辺りから上手く起動出来なくなる
hplのソース再コンパイルで直った
ネットワークが繋げない

デフォルトのWifiが弱すぎる
カメラの画角,高さ(肩などで見れない範囲が多い)
バッテリー過放電させた,やはりアラームが必要
コンパイルが遅すぎる
モーションクリエイターが無い
ポーズイニシャライズが上手く動かない
サーボの値が読めない
リンクパラメータ
チルト角
モーションの再生速度指定が出来ない
HR42等の自動起動
サーボON後出ないとうまくいかない?
rc.localにカメラの情報
LANポートが低すぎる
GPIOスイッチのコード
取手が持ちにくい
取手が緩い
初期値の調整が出来てない?
長穴で逆動作してしまう
トルクリミッター
歩行パラメータ(歩き出し)がオカシイ

takayan660, 2017-07-24:
腕のサブレーム（COM）がなめる
クロワッシャーの設計変更

takayan660, 2017-09-23:
csi2のカメラ(OP性を補うため）

yasuohayashibara, 2017-11-27:
こちら未解決で重要と思われる問題に関しては，別途issueを立ち上げて下さい．

yasuohayashibara, 2019-05-13:
こちらほぼ対処できたと思いますので，issueを閉じます．

Closed 2019-05-13.

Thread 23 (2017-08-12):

キック力が弱い

yasuohayashibara, 2017-08-12:
ロボカップでシュートするのに対して，足先の先端速度が低い．

yasuohayashibara, 2017-08-12:
従来のKONDOと比べておよそ半分の速度になっている．
ちなみに，Dynamo (Acceliteの前) のボール速度は 2.5m/s という記録がある．

■ KONDO B3M-SC-1170-A
モータの最大回転数 46 rpm
4.81 rad/s
2.40 rad/s

股から足先 0.2	m
0.481 m/s
膝から足先 0.1	m
0.240 m/s

足先の速度
0.722 m/s

■ FUTABA RS405CB
モータの最大回転数 45 rpm
4.71 rad/s
股から足先 0.22 m
1.036 m/s
膝から足先 0.11 m
0.518 m/s

足先の速度
1.555 m/s

yasuohayashibara, 2017-08-12:
上記計算のスプレッドシート
[170813足先速度の計算.xlsx](https://github.com/citbrains/OpenPlatform/files/1220089/170813.xlsx)

yasuohayashibara, 2017-11-27:
実ロボットにおける検証

世界大会で開発したシュート
https://youtu.be/hlHyPo2hQXU
https://youtu.be/tprLfQ_ZzIM

支持脚のヨー軸を積極的に動かすシュートモーション
https://youtu.be/x_8HCoAuvjk
※飛距離を重視したため，安定性は無視している．

３ｍ程度安定してシュートできている．

yasuohayashibara, 2017-11-27:
意見があればお願いします．

例えば，
こちらもっと良い方法がある．
３ｍでシュート距離は十分である．
ハードウェアの改良が必要である．
など

SatoshiShimada, 2017-11-28:
シュート距離は3mあれば十分だと思います。
安定性を無視しているとありますが、手で支えなくてもキックできるのでしょうか？(動画からは支えているか判断できませんでした。)

takayan660, 2017-11-28:
手で支えてあげないと、キックする前に体勢を崩します
ですので、キック力はどこまでいけるか確認できたので、これからは体勢を崩さないようにできるキックモーションを考察する予定です

yasuohayashibara, 2017-12-16:
1.5mボールを転がすシュートを蹴れるようになったので，issueを閉じます．

Closed 2017-12-16.

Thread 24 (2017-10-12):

部品発注リスト作成

yoshiya01, 2017-10-12:
Ver.1からVer.2に至るに辺り,既製品の発注リストが不完全になっていました。今後のため発注リストを整理します。

yoshiya01, 2017-10-12:
ローカルで作業していたものをオンラインで各員が確認できるようにドライブにアップしました。最終的にはリストファイル自体をgitに上げる予定です。https://docs.google.com/spreadsheets/d/1T-6h962NMB8wy8rFKbgDF4RVcZlRBI_5iQs3WqfAVWs/edit?usp=sharing

yasuohayashibara, 2017-10-26:
１）以下に関して１台分の個数を示して下さい．
LL-7211-08
T6068-4530
D4050-9120B
D3040-7815B
BRU-306_5S
ARU-305_5
ASL-340BE
BRU-305_5

２）以下など，ミスミでエラーになりますので，表記を変更して下さい．
BRU-305_5

305_5 -> 305.5 に変更

yasuohayashibara, 2019-05-13:
バージョン3に移行しましたので，こちらのissueを閉じます．

Closed 2019-05-13.

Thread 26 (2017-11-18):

入手性の良い広角カメラの検討

yasuohayashibara, 2017-11-18:
以下に入手性の良い広角カメラを見つけた．
https://www.switch-science.com/catalog/3211/

入手性や価格で有利であるため，こちらを採用することを検討する．
ちなみに，TX1にも接続できそうな気がする．
(議論されているのはRaspberry Camera V2ですが，おそらく互換性はあると思います．)
https://devtalk.nvidia.com/default/topic/972364/raspberry-camera-v2-Raspberry Camera-csi-with-jetson-tx1-j100-carrier-board/?offset=6

yasuohayashibara, 2017-11-20:
１個購入しました．

yasuohayashibara, 2017-11-27:
カメラ取り付けの様子（両面テープで貼り付けただけです）
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

撮影した画像（足元にボールを置き，カメラを下向きに傾けました．場所はキックオフの位置）
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

最大解像度2592 x 1944でキャプチャした画像の画面をキャプチャしたので，解像度は適当

結果的に，足元のボールもゴールラインのボールも両方視野内に入っている．
おそらく現在使用しているカメラでの画像とそれほど違わないと思われる．

yasuohayashibara, 2017-11-27:
OpenPlatformではこちらのカメラをまずは採用したいと思いますが，意見がありましたらお願いします．

SatoshiShimada, 2017-11-28:
ケーブルの取り回しが悪いため実戦投入が心配ですがどのようにお考えでしょうか。

yasuohayashibara, 2017-11-29:
実験はしていませんが，フラットケーブルの途中を割いてまとめると屈曲に対する耐性が上がるとの情報がありました．

あとは，最悪途中に変換基板を入れて対処することもできると思いますが，こちらが手間が多いですね．
フラットケーブル　→　基板　→　シリコンケーブル　→　基板　→　フラットケーブル

ちなみに，何もせずそのままで市販しているロボットもあります．
http://www.botmag.com/raspberry-pi-camera-robot/

SatoshiShimada, 2017-11-29:
割いて使用するのは信頼性が薄いので不安が残ります。
基盤を途中にいれるのは良いアイデアだと思いますが、あまり新規開発の案件を増やしたくないため、より一般的なUSBカメラでもよいのではないでしょうか。
#29 でチルト軸を扱うようになっているので広角カメラである必要もないのではないかと考えます。

yasuohayashibara, 2017-11-30:
意見ありがとう．
多方面からの意見がシステムの完成度を上げると思いますので，議論していきましょう．

基板にMIPI CSI-2のコネクタがあるので，試してみたいというのが一番ですが，実際にどちらが良いかは動かしてみて判断するのでも良いかと思います．
ケーブルに関しては，あまり検証はできていませんが，割かなくても動作することは動作します．
まずは，問題が発生するまで動かすことが重要かなと考えています．

USBに関してですが，複数のデバイスから多くのデータを流すとシステムが実時間で動かなくなることを経験していますので，その点でMIPIを採用した時にどのような変化があるかというのを検証したいと考えています．
実はこの件で一番影響を受けるのは歩行の安定性ではないかと考えています．

広角カメラに関してですが，狭角のカメラを当初は採用することを考えていましたが，現在の画像処理および戦略の開発リソースを見る限り，チルトも含めた画像処理システムを作り直すことは難しいと思いますので，まずは現在のカメラと同じ広角カメラで構成したほうが良いと考えています．

とにかく作って動かしてデータを取ることが必要だと考えています．

SatoshiShimada, 2017-11-30:
ありがとうございます。確かに安定して動作するなら採用したいですしそのためにも試しておくべきですね。

yasuohayashibara, 2017-12-11:
議論が一度収束したので，issueを閉じます．
再度議論する必要があれば，オープンします．

Closed 2017-12-11.

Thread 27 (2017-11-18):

衝撃吸収機構に関する検討

yasuohayashibara, 2017-11-18:
衝撃吸収機構の検討を行う．
仕様：
１）足元前方のボール全体をカメラで撮影できる．
２）ロボットへの最大加速度を40G以下にする．

yasuohayashibara, 2017-11-19:
少々検討の順番が入れ替わっているが，#29 のように頭を伸ばすことで48mmほどの衝撃吸収のためのスペースができる．

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

yasuohayashibara, 2017-11-21:
@shutotakano 先日議論した時のメモ書きですが，参考までにアップします．
きちんとした検証を行なっていないので，あくまでも参考まで．

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

yasuohayashibara, 2017-11-27:
特に意見が無さそうであるため，こちらに示した機構の配置で設計を行います．
こちらのissueを閉じます．

Closed 2017-11-27.

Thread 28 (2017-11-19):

腕の長さの検討

yasuohayashibara, 2017-11-19:
腕の長さが足りないために起き上がりをしづらい．
適正な腕の長さを求める．

yasuohayashibara, 2017-11-19:
現在の腕の長さ
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

おそらく腕の長さを制限するロボカップのルールは以下となる．
• The robot does not possess a conﬁguration where it is extended longer than 1.5·Htop .

身長　　　608mm
腕の長さ　246.5mm
肩幅　　　183mm
で，(608 * 1.5 - 183 - 2 * 246.5) / 2 = 118

片腕118mm延長してもルール上は問題ない．

yasuohayashibara, 2017-11-19:
一方起き上がりに必要な腕の長さの検討
60mm程度伸ばせば起き上がりできると考える．

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

yasuohayashibara, 2017-11-19:
肩から肘までを40mm，肘から手先までを30mm伸ばして，合計70mm伸ばしたときの様子

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

この程度の長さの余裕があれば，問題なく起き上がりできると考える．

yasuohayashibara, 2017-11-19:
検討してみました．
抜けがあればご指摘ください．

yasuohayashibara, 2017-11-19:
直立したときの外観は以下のようになる．
（腕をまっすぐ伸ばすと干渉します．）

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

takayan660, 2017-11-19:
少し議論内容から離れているような気がしますが、今の腕先ですと芝生に引っかかる可能性があり、それですと起き上がりに支障をきたすおそれがあるので、3号機のように腕先の面積を増やし丸めた方が良いかと思われます。

写真は3号機の腕先です。
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

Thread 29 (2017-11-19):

カメラの位置の検討

yasuohayashibara, 2017-11-19:
カメラの位置を検討する．
現在はバンパーがあるために足元のボールを見ることができない．

yasuohayashibara, 2017-11-19:
最も簡単な対処法はチルト軸からカメラまでの距離を長くすることである．

身長が608mmとして，許される首の長さは，
30.4mmから152mm　(肩関節軸からの長さ)

現在は角も含めて113mmであるため，これを40mm程度伸ばす．
ただし，身長が伸びると許容される首の長も長くなるため，それを踏まえた設計を行う．

yasuohayashibara, 2017-11-19:
少々格好悪いが，単純に46mm延長したときの外観を示す．
許容される首の長さ163mmに対して，159mmとなる．

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

#26 で示したカメラを取り付けたときに足元を見るためにはピッチ方向に30deg傾ければ十分であるため，図のようになる．これで全方すべてを視野内に収めることができる．
（その分解像度は低いが．．．）

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

背面も見ることができる．（ピッチ方向に60deg）
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

yasuohayashibara, 2017-11-19:
見落としている点があればご指摘ください．

yasuohayashibara, 2017-11-27:
特に意見が無さそうであるので，首を長くする方向で改良を行います．
こちらのissueを閉じます．

Closed 2017-11-27.

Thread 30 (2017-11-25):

歩行の安定化

yasuohayashibara, 2017-11-25:
人工芝の上では安定して歩行できないという報告があったので確認して，安定するように調整する．

yasuohayashibara, 2017-11-25:
床での足踏み
https://youtu.be/MQ7JBiYOOo8

人工芝での足踏み
https://youtu.be/b2Q9AaWK58A

yasuohayashibara, 2017-11-25:
前後左右に歩行する時に不安定になるとの報告あり．
動画を撮る．

yasuohayashibara, 2017-11-25:
動画を撮影した．
人工芝になることで，接地のタイミングや芝に足先が絡むことで不安定な歩行になっている．
ジャイロフィードバックをもっと積極的に使用した方が良いと思われる．

その場足踏み
https://youtu.be/HZ9H2LmXmZo

前進
https://youtu.be/7uHzApsEUhM

後退
https://youtu.be/s1Vgd2PuVlM

左
https://youtu.be/dRysnTMjW6I

右
https://youtu.be/rQsaMAQu4wo

yasuohayashibara, 2017-11-25:
ジャイロフィードバックを積極的に追加した歩行
明らかに安定するようになった．
左右に関しては歩幅が大きいと不安定になる．

https://youtu.be/NTv1iwL2UPg

yasuohayashibara, 2017-11-25:
左右の歩行が安定しない要因の一つに足先の角度があると考えられる．

以下，足先の様子
https://youtu.be/x01cYEkjXqI

本来は腰と平行に上下するように制御しているはずであるが，股ロールと足首ロールの同期が取れていないため，上げた時に足先が傾いている．

yasuohayashibara, 2017-11-25:
制御周期を1/10にして制御した時の足先の傾き
https://youtu.be/2dIhiTnlL1g

明らかに足先のロール角度の変化が緩やかになっている．
股ロール軸の遅れが問題になっていると思われる．

yasuohayashibara, 2017-11-26:
ジャイロフィードバックが入っていたので，ゲインを０にしてその場足踏みを行なった．
角度の変化が緩やかになり，ジャイロの影響であることが分かった．
https://youtu.be/wc7C76Lgq_M

yasuohayashibara, 2017-11-27:
横歩き時に不安定になる要因が判明

eeprom_list.txt内に以下のパラメータがあるが，つっかかりを減らすために遊脚時には歩行中に足先を進行方向に傾ける仕様になっており，これが問題を発生させていた．

86	3.0			xp_mv_walk.foot_cntl_r

着地のタイミングが理想的であればよいが，早すぎると傾いたまま着地してしまい，横移動時に不安定な歩行となる．

値に０を代入した時の歩行
https://www.youtube.com/edit?o=U&video_id=MGoJsLShtz8

ちなみに，上記歩行では以下のパラメータも０になっている．
87	0.1			xp_mv_walk.sidestep_time_k
88	1.5			xp_mv_walk.sidestep_roll

yasuohayashibara, 2017-11-27:
３号機で試した様子（歩行の周期が長い）

xp_mv_walk.foot_cntl_rを0
https://youtu.be/2vnVDU9-_PY

ジャイロフィードバックを積極的に入れる
https://youtu.be/VFg9KHkk24o

試合形式での確認（シュート無し）
https://youtu.be/e6-gN8QUuio
※なぜか歩行周期が遅くなるときがある．(Jetson-TX1搭載)

yasuohayashibara, 2017-11-27:
ほぼ安定して歩行できるようになったと思われるため，issueを閉じます．

Closed 2017-11-27.

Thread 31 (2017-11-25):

Gankenkunの破損報告

takayan660, 2017-11-25:
Gankenkunのモーションを作成しようとしたところハードウェアの破損を見つけたので報告します。

* 膝部分でガラスエポキシのリンクが干渉している
 干渉していることにより手で回転させると他より大きな抵抗を感じます。
 左右両足で内側, 外側の計4箇所で発生しています。
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

* 股のロール軸サーボ周り
  * サーボの出力軸と反対側の軸が板金と干渉している
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
  * サーボの出力軸側の面に固定されている板金の破損
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

takayan660, 2017-11-25:
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

>・股のロール軸サーボ周り
>3DCAD図
>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

>図面ではギャップがあります．先ほど確認したら部品（ワッシャ）が不足していました．

takayan660, 2017-11-25:
>ガラエポの問題について対応しました.すべての箇所図のように削りました.
>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

SatoshiShimada, 2017-11-25:
https://github.com/citbrains/citbrains_humanoid/issues/816 こちらで議論したものを引継いでいます。
以降はこちらで議論しましょう。

shutotakano, 2017-11-27:
股のロール軸サーボ周りについて
不足していたワッシャーを加えました.
間隔があいたことを確認しました.
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

yasuohayashibara, 2017-11-27:
問題の確認と対策ができたと思われますので，こちらのissueを閉じます．

shutotakano, 2018-05-05:
13番サーボ(1170-A)がしゃがんている状態で180°命令をして発熱,破損.
長穴機構のネジが緩み,ガラエポと干渉,サーボが大きな抵抗を受け発熱,破損.
写真は後者の破損のものです.
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

Closed 2017-11-27.

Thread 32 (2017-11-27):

長い腕の設計

yasuohayashibara, 2017-11-27:
#28 で示された指針に従って長い腕を設計する．

yasuohayashibara, 2017-12-10:
腕を設計した．

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

そのまま伸ばすと腰とアームが干渉するので，肘が無かった頃のAcceliteのように単純に板を伸ばすようにした．
強度的な問題があるかもしれないが，転倒実験により検証する．

yasuohayashibara, 2017-12-10:
加工した．

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

yasuohayashibara, 2017-12-10:
設計・製作したのでissueを閉じます．

yasuohayashibara, 2017-12-12:
片腕だけ取り付けた様子

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

かなり余裕があることを確認した．(70mm伸ばしています．)

yasuohayashibara, 2017-12-12:
腕を長くした後の歩行
（まあ変わる要素はそれほど無いですが．．．）

https://youtu.be/z2ZWSnlc7bo

Closed 2017-12-10.

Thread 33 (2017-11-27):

首と衝撃吸収機構の設計

yasuohayashibara, 2017-11-27:
#29 #27 の方針に従って，首と衝撃吸収機構を設計する．

yasuohayashibara, 2017-12-10:
頭を設計した．
POMで2017をつなぐ構造で，強度が心配ではあるが，転倒させて問題があれば改良する．

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

曲げで精度を出すのが大変だったのと5052の加工が難しかったので，こちらの方が作りやすいかもしれない．

yasuohayashibara, 2017-12-11:
製作した首のパーツ

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

あっ．カメラの取り付け位置の穴が逆．．．

yasuohayashibara, 2017-12-11:
問題を切り分けて，衝撃吸収機構の設計に関しては， #35 に引き継ぎます．
首の設計・製作が終了したのでissueを閉じます．

yasuohayashibara, 2017-12-12:
首を取り付けた．

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

Closed 2017-12-11.

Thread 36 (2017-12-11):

音声出力するデバイスの調査

yasuohayashibara, 2017-12-11:
RaspberryPIにおいてI2S通信で音声を出力するデバイスを調査する．

yasuohayashibara, 2017-12-11:
以下のスピーカを購入した．
Pimoroni Speaker pHAT - スピーカー
https://www.amazon.co.jp/dp/B01N2A4RGM/ref=pe_1807052_198774502_tnp_email_dp_1

8Ω 2W マイラー スピーカー、デフォルト出力 0.45W/26.5dB

yasuohayashibara, 2017-12-11:
音を出力したところ音量が小さかったが，0.45Wは通常のスマート・フォンのスピーカ程度とのことです．何かまだ設定していないところがあるかもしれません．

音を大きくする方法は以下で紹介されているようです．
https://forums.pimoroni.com/t/doubt-about-the-real-power-of-speaker-phat/4541

yasuohayashibara, 2018-01-04:
音を出力することができた．
https://youtu.be/o8gdnzREft4

当初以下の通りインストールしても動作しなかった．
https://shop.pimoroni.com/products/speaker-phat

以下のファイルを消去して，再起動することで音が出力されるようになった．
/etc/asound.conf

おそらくは周りが騒がしくてもそこそこ聞こえるぐらいの音量になっていると考える．
ただし，現在音量の調整ができない．

yasuohayashibara, 2018-01-04:
調査したので，issueを閉じます．
高須君，セットアップ及び調査ありがとうございます．

yasuohayashibara, 2018-01-04:
フィールドでも試してみた．
https://youtu.be/6NI4xzJtYNI

警告音のような音であれば，充電器の終了時の音と同じ程度周囲に聞こえることを確認した．
歴代のスピーカに比べて特に音が小さいということは無い．

フィールドで確かめて問題なかったため，こちらを採用する．

Closed 2018-01-04.

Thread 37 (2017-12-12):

首を長くした時の視野の確認

yasuohayashibara, 2017-12-12:
首を長くして，広角カメラ #26 を付けた場合の画像を確認する．

首を長くした場合の設計
https://github.com/citbrains/OpenPlatform/tree/long_head

yasuohayashibara, 2017-12-12:
条件としては，時間が無かったので昼に真上のライトを付けずに撮影
かなり暗めであったが，割と明るく撮影できていた．

まずは中央でまっすぐ上に向けた時の様子
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

取得した画像
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

足元を見ている様子
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

取得した画像
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

カメラを水平にした時の画像（ルール違反です）
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

取得した画像
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

そう言えば後ろを向いた時の画像が無かった．．．

yasuohayashibara, 2017-12-12:
確認したのでissueを閉じます．

Closed 2017-12-12.

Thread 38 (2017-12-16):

raspberry PI3でのボールの認識

yasuohayashibara, 2017-12-16:
raspberry PI3でのボールの認識に関して確認する．
ちなみに，カメラは広角カメラ #26
オートホワイトバランスなどは固定せずに画像処理をしている．

yasuohayashibara, 2017-12-16:
ボール認識の様子
https://youtu.be/HrCiLgHgEGA

適当なパラメータだが比較的ボールを認識できている．
途中で色が変化したのかロストした．
オートの機能を停止することが必要．

yasuohayashibara, 2017-12-16:
確認したのでissueを閉じます．

Closed 2017-12-16.

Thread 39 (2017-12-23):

ルールに基づく寸法の制限

yasuohayashibara, 2017-12-23:
ルールに基づく寸法の制限を示す表計算のデータをアップする．

yasuohayashibara, 2017-12-23:
アップします．
[ルールに基づく寸法の制限.xlsx](https://github.com/citbrains/OpenPlatform/files/1583878/default.xlsx)

yasuohayashibara, 2017-12-23:
アップしたのでissueを閉じます．

Closed 2017-12-23.

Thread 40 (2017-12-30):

リンクパラメータの導出

yasuohayashibara, 2017-12-30:
歩行制御のためにリンクパラメータを求める．

yasuohayashibara, 2017-12-30:
3DCADから以下の寸法を取得した．
示していない寸法は差が0mm（もしくは0.1mm以下）のところです．
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

yasuohayashibara, 2017-12-30:
リンクパラメータですが，以下のようになりました．
検証不足のため，修正するおそれがあります．

```
/*
 * @file		LinkParameter_GankenKun.h
 * @brief		Constant Value of Link for Humanoid Robot
 * @author		Yasuo Hayashibara
 * @date		2017/12/30
 */

#ifndef _LINK_PARAMETER_GANKENKUN_
#define _LINK_PARAMETER_GANKENKUN_

#include <iostream>
#include <string>
#include <Eigen/Dense>
#include <limits>
#include <boost/math/constants/constants.hpp>

using namespace std;
using namespace Eigen;

const int NON = -1;
static const double eps = 1e-06;
static const double pi = boost::math::constants::pi<double>();

enum {							//! サーボの番号
	ANKLE_ROLL_R		=	1,	//! 右足首のロール軸
	ANKLE_PITCH_R		=	2,	//! 右足首のピッチ軸（シリアルリンク)
	LOWER_KNEE_PITCH_R	=	3,	//! 右足膝下ピッチ軸（平行リンク）
	UPPER_KNEE_PITCH_R	=	4,	//! 右足膝上ピッチ軸（平行リンク）
	HIP_ROLL_R			=	5,	//! 右股のロール軸
	HIP_YAW_R			=	6,	//! 右股のヨー軸
	SHOULDER_PITCH_R	=	7,	//! 右肩のピッチ軸
	SHOULDER_ROLL_R		=	8,	//! 右肩のロール軸
	ELBOW_PITCH_R		=	9,	//! 右肘のピッチ軸
	ANKLE_ROLL_L		=	10,	//! 左足首のロール軸
	ANKLE_PITCH_L		=	11,	//! 左足首のピッチ軸（シリアルリンク)
	LOWER_KNEE_PITCH_L	=	12,	//! 左足膝下ピッチ軸（平行リンク）
	UPPER_KNEE_PITCH_L	=	13,	//! 左足膝上ピッチ軸（平行リンク）
	HIP_ROLL_L			=	14,	//! 左股のロール軸
	HIP_YAW_L			=	15,	//! 左股のヨー軸
	SHOULDER_PITCH_L	=	16,	//! 左肩のピッチ軸
	SHOULDER_ROLL_L		=	17,	//! 左肩のロール軸
	ELBOW_PITCH_L		=	18,	//! 左肘のピッチ軸
	HEAD_YAW			=	19,	//! 首のヨー軸
	HEAD_PITCH			=	20,	//! 首のピッチ軸
	JOINT_NUM
};

enum {			// リンクの番号
	CAM	,		//! カメラのリンク（光軸を求めるため）
	HT	,		//! 頭のチルト軸からカメラ (Acceliteは固定)
	HP	,		//! 頭のパン軸からチルト軸
	SH	,		//! 肩中心から頭のパン軸
	CS	,		//! 腰から肩中心
	CC	,		//! 腰（基点）
	RY	,		//! 右股ヨー軸から右股ロール軸
	RR1	,		//! 右股ロール軸から右膝上ピッチ軸
	RP1	,		//! 右膝上ピッチ軸から右膝下ピッチ軸
	RP2	,		//! 右膝下ピッチ軸から右足首ピッチ軸
	RP3	,		//! 右足首ピッチ軸から右足首ロール軸
	RR2	,		//! 右足首ロール軸から右足先
	RF  ,		//! 右足先
	LY	,		//! 左股ヨー軸から左股ロール軸
	LR1	,		//! 左股ロール軸から左膝上ピッチ軸
	LP1	,		//! 左膝上ピッチ軸から左膝下ピッチ軸
	LP2	,		//! 左膝下ピッチ軸から左足首ピッチ軸
	LP3	,		//! 左足首ピッチ軸から左足首ロール軸
	LR2	,		//! 左足首ロール軸から左足先
	LF  ,		//!	左足先
	RSP ,		//! 右肩ピッチ軸から肩ロール軸
	RSR	,		//! 右肩ロール軸から肘ピッチ軸
	RER	,		//! 右肘ピッチ軸から右腕先端
	RH  ,		//! 右腕先端
	LSP ,		//! 左肩ピッチ軸から肩ロール軸
	LSR	,		//! 左肩ロール軸から肘ピッチ軸
	LER	,		//! 左肘ピッチ軸から左腕先端
	LH  ,		//! 左腕先端
	LINK_NUM	//! リンクの数
};

struct link_connect
{
	int sister;
	int child;
	int parent;
};

static const struct link_connect LINK_CONNECT[LINK_NUM] =
{
	{ NON, NON, HT  },	// CAM : カメラのリンク（光軸を求めるため）
	{ NON, CAM, HP  },	// HT  : 頭のチルト軸からカメラ (Acceliteは固定)
	{ NON, HT , SH  },	// HP  : 頭のパン軸からチルト軸
	{ NON, HP , CS  },	// SH  : 肩中心から頭のパン軸
	{ NON, SH , CC  },	// CS  : 腰から肩中心
	{ RY , CS , NON },	// CC  : 腰（基点）
//	腰 -> 右足先
	{ LY , RR1, CC  },	// RY  : 右股ヨー軸から右股ロール軸
	{ NON, RP1, RY  },	// RR1 : 右股ロール軸から右膝上ピッチ軸
	{ NON, RP2, RR1 },	// RP1 : 右膝上ピッチ軸から右膝下ピッチ軸
	{ NON, RP3, RP1 },	// RP2 : 右膝下ピッチ軸から右足首ピッチ軸
	{ NON, RR2, RP2 },	// RP3 : 右足首ピッチ軸から右足首ロール軸
	{ NON, RF , RP3 },	// RR2 : 右足首ロール軸から右足先
	{ NON, NON, RR2 },	// RF  : 右足先
//	腰 -> 左足先
	{ RSP, LR1, CC  },	// LY  : 左股ヨー軸から左股ロール軸
	{ NON, LP1, LY  },	// LR1 : 左股ロール軸から左膝上ピッチ軸
	{ NON, LP2, LR1 },	// LP1 : 左膝上ピッチ軸から左膝下ピッチ軸
	{ NON, LP3, LP1 },	// LP2 : 左膝下ピッチ軸から左足首ピッチ軸
	{ NON, LR2, LP2 },	// LP3 : 左足首ピッチ軸から左足首ロール軸
	{ NON, LF , LP3 },	// LR2 : 左足首ロール軸から左足先
	{ NON, NON, LR2 },	// LF  : 左足先
//	肩中心 -> 右手先
	{ LSP, RSR, CS  },	// RSP : 右肩ピッチ軸から右肩ロール軸
	{ NON, RER, RSP },	// RSR : 右肩ロール軸から右肘ピッチ軸
	{ NON, RH , RSR },	// RER : 右肘ピッチ軸から右腕先端
	{ NON, NON, RER },	// RH  : 右腕先端
//	肩中心 -> 左手先
	{ NON, LSR, CS  },	// LSP : 左肩ピッチ軸から左肩ロール軸
	{ NON, LER, LSP },	// LSR : 左肩ロール軸から左肘ピッチ軸
	{ NON, LH , LSR },	// LER : 左肘ピッチ軸から左腕先端
	{ NON, NON, LSR },	// LH  : 左腕先端
};

static const double LinkAxis[LINK_NUM][3] = {
//	{{  前後,   左右,   上下},{前後軸,左右軸,上下軸}} (mm)
//	腰 -> 頭
	{  0.0f,  0.0f,  0.0f},	// CAM : カメラのリンク（光軸を求めるため）
	{  0.0f,  0.0f,  0.0f},	// HT  : 頭のチルト軸からカメラ (Acceliteは固定)
	{  0.0f,  1.0f,  0.0f},	// HP  : 頭のパン軸からチルト軸
	{  0.0f,  0.0f,  1.0f},	// SH  : 肩中心から頭のパン軸
	{  0.0f,  0.0f,  0.0f},	// CS  : 腰から肩中心
	{  0.0f,  0.0f,  0.0f},	// CC  : 腰（基点）
//	腰 -> 右足先
	{  0.0f,  0.0f,  1.0f},	// RY  : 右股ヨー軸から右股ロール軸
	{  1.0f,  0.0f,  0.0f},	// RR1 : 右股ロール軸から右膝上ピッチ軸
	{  0.0f,  1.0f,  0.0f},	// RP1 : 右膝上ピッチ軸から右膝下ピッチ軸
	{  0.0f,  1.0f,  0.0f},	// RP2 : 右膝下ピッチ軸から右足首ピッチ軸
	{  0.0f,  1.0f,  0.0f},	// RP3 : 右足首ピッチ軸から右足首ロール軸
	{  1.0f,  0.0f,  0.0f},	// RR2 : 右足首ロール軸から右足先
	{  0.0f,  0.0f,  0.0f},	// RF  : 右足先
//	腰 -> 左足先
	{  0.0f,  0.0f,  1.0f},	// LY  : 左股ヨー軸から左股ロール軸
	{  1.0f,  0.0f,  0.0f},	// LR1 : 左股ロール軸から左膝上ピッチ軸
	{  0.0f,  1.0f,  0.0f},	// LP1 : 左膝上ピッチ軸から左膝下ピッチ軸
	{  0.0f,  1.0f,  0.0f},	// LP2 : 左膝下ピッチ軸から左足首ピッチ軸
	{  0.0f,  1.0f,  0.0f},	// LP3 : 左足首ピッチ軸から左足首ロール軸
	{  1.0f,  0.0f,  0.0f},	// LR2 : 左足首ロール軸から左足先
	{  0.0f,  0.0f,  0.0f},	// LF  : 左足先
//	肩中心 -> 右手先
	{  0.0f,  1.0f,  0.0f},	// RSP : 右肩ピッチ軸から右肩ロール軸
	{  1.0f,  0.0f,  0.0f},	// RSR : 右肩ロール軸から右肘ピッチ軸
	{  0.0f,  1.0f,  0.0f},	// REP : 右肘ピッチ軸から右腕先端
	{  0.0f,  0.0f,  0.0f},	// RH  : 右腕先端
//	肩中心 -> 左手先
	{  0.0f,  1.0f,  0.0f},	// LSP : 左肩ピッチ軸から左肩ロール軸
	{  1.0f,  0.0f,  0.0f},	// LSR : 左肩ロール軸から左肩ピッチ軸
	{  0.0f,  1.0f,  0.0f},	// LEP : 左肩ピッチ軸から左腕先端
	{  0.0f,  0.0f,  0.0f},	// LH  : 左腕先端
};

static const double LinkPos[LINK_NUM][3] = {
//	{{  前後,   左右,   上下},{前後軸,左右軸,上下軸}} (mm)
//	腰 -> 頭
	{300.0f,   0.0f,   0.0f},	// CAM : カメラのリンク（光軸を求めるため）
	{ 31.4f,   0.0f,   0.0f},	// HT  : 頭のチルト軸からカメラ (Acceliteは固定)
	{  0.0f,   0.0f,  31.3f},	// HP  : 頭のパン軸からチルト軸
	{  0.0f,   0.0f,  21.8f},	// SH  : 肩中心から頭のパン軸
	{ -5.0f,   0.0f, 144.5f},	// CS  : 腰から肩中心
	{  0.0f,   0.0f,   0.0f},	// CC  : 腰（基点）
//	腰 -> 右足先
	{  0.0f, -44.0f,   0.0f},	// RY  : 右股ヨー軸から右股ロール軸
	{  0.0f,   0.0f, -51.0f},	// RR1 : 右股ロール軸から右股ピッチ軸
	{  8.4f,   0.0f,   0.0f},	// RP1 : 右股ピッチ軸から右膝上ピッチ軸
	{  0.0f,   0.0f,-100.0f},	// RP2 : 右膝上ピッチ軸から右膝下ピッチ軸
	{  0.0f,   0.0f, -57.0f},	// RP3 : 右膝下ピッチ軸から右足首ピッチ軸
	{  0.0f,   0.0f,-100.0f},	// RP4 : 右足首ピッチ軸から右足首ロール軸
	{  0.0f,   0.0f,   0.0f},	// RR2 : 右足首ロール軸から右足先
	{  0.0f,   0.0f, -43.0f},	// RF  : 右足先
//	腰 -> 左足先
	{  0.0f,  44.0f,   0.0f},	// LY  : 左股ヨー軸から左股ロール軸
	{  0.0f,   0.0f, -51.0f},	// LR1 : 左股ロール軸から左股ピッチ軸
	{  8.4f,   0.0f,   0.0f},	// LP1 : 左股ピッチ軸から左膝上ピッチ軸
	{  0.0f,   0.0f,-100.0f},	// LP2 : 左膝上ピッチ軸から左膝下ピッチ軸
	{  0.0f,   0.0f, -57.0f},	// LP3 : 左膝下ピッチ軸から左足首ピッチ軸
	{  0.0f,   0.0f,-100.0f},	// LP4 : 左足首ピッチ軸から左足首ロール軸
	{  0.0f,   0.0f,   0.0f},	// LR2 : 左足首ロール軸から左足先
	{  0.0f,   0.0f, -43.0f},	// LF  : 左足先
//	肩中心 -> 右手先
	{  0.0f, -91.5f,   0.0f},	// RSP : 右肩ピッチ軸から右肩ロール軸
	{  0.0f,   0.0f, -84.0f},	// RSR : 右肩ロール軸から右肘ピッチ軸
	{  0.0f,   0.0f,   0.0f},	// REP : 右肘ピッチ軸から右腕先端
	{  0.0f,   0.0f,-162.5f},	// RH  : 右腕先端
//	肩中心 -> 左手先
	{  0.0f,  91.5f,   0.0f},	// LSP : 左肩ピッチ軸から左肩ロール軸
	{  0.0f,   0.0f, -84.0f},	// LSR : 左肩ロール軸から左肩ピッチ軸
	{  0.0f,   0.0f,   0.0f},	// LEP : 左肩ピッチ軸から左腕先端
	{  0.0f,   0.0f,-162.5f},	// LH  : 左腕先端
};

#endif
```

yasuohayashibara, 2017-12-30:
リンクパラメータを導出したのでissueを閉じます．

Closed 2017-12-30.

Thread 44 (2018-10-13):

ver.3.0用の部品購入

yasuohayashibara, 2018-10-13:
ver.3.0用に以下を購入する．

メーカ | 型番 | 個数
-- | -- | --
MISUMI | ALSFB6-66 | 5
ウィルコ | ASU-340 | 15
MISUMI | SETF5-63.5-M3-N3 | 5
MISUMI | SETF5-55.5-M3-N3 | 5
MISUMI | SLCG5_5-6 | 55
MISUMI | SLCG5_5-8 | 5
MISUMI | MF85ZZ | 50
KONDO | ベアリング付アルミフリーホーン 6個セット | 6
MISUMI | AXK1105 | 25
MISUMI | AS2542 | 16

yasuohayashibara, 2018-10-13:
ASU-340は残数があると思われるので発注していないが，他は全て発注しました．

yasuohayashibara, 2018-10-13:
発注したのでissueを閉じます．

Closed 2018-10-13.

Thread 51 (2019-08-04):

ver.3の製作

yasuohayashibara, 2019-08-04:
7台目のver.3を製作する．

yasuohayashibara, 2019-08-04:
多くの部品は今までに切削した部品が利用できるが，一部不足するものもあるので，切削を行う．

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

yasuohayashibara, 2019-08-04:
切削済みのパーツ

ネジなどのパーツ
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

切削したパーツ１
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

切削したパーツ２
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

yasuohayashibara, 2019-08-04:
製作した部品のリスト（リストはInventorで自動的に製作）

https://docs.google.com/spreadsheets/d/1V7p6FwAAQF0EGcoJ-RnF4YOk1j_0ebExYPMp1_4gwCU/edit?usp=sharing

yasuohayashibara, 2019-08-06:
合間を見つけて作成していたのと，不足していた部品もあったので，ここまでで終了です．
今月末までの完成を目指します．

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

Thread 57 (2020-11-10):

DT-30N（静岡鉄工所）を用いた部品の切削

yasuohayashibara, 2020-11-10:
DT-30N（静岡鉄工所）を用いた部品の切削に関してログを残す．

yasuohayashibara, 2020-11-10:
加工に際して用意した部品

- エンドミル
XAL-PEM2LB2-14
XAL-PEM2R2
XAL-PEM2R4
XAL-PEM2R6

- 切削台
PAA-300-300-30
RCDM10

- 両面テープ
5000NS-20

yasuohayashibara, 2020-11-17:
加工用のテーブルを取り付けて面出し加工を行う準備を行った．

動画
https://youtu.be/yd_gfb8MrxA

面出し加工用のデータ
[SurfaceProcessing.zip](https://github.com/citbrains/OpenPlatform/files/5552044/SurfaceProcessing.zip)

yasuohayashibara, 2020-11-18:
面出し加工できました．

https://youtu.be/edY9PH9VGPo

まだ手順の最適化はできていません．
特に基準となる位置は手打ちで微調整を行っていますので，なんとかしないと効率が悪いです．

yasuohayashibara, 2020-11-19:
多くの試行錯誤の末，ようやく切削できるようになりました．
剛性が高いので安心して見ていられます．

https://youtu.be/t5S8own3hxY

yasuohayashibara, 2020-11-20:
切削ができるようになったので，こちらのissueを閉じます．

Closed 2020-11-20.

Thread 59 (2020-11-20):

DT-30N（静岡鉄工所）の切削マニュアル

yasuohayashibara, 2020-11-20:
#57 からの引き継ぎ

DT-30N（静岡鉄工所）の切削マニュアルを作成する．

yasuohayashibara, 2020-11-23:
作成途中の切削マニュアル
https://docs.google.com/document/d/1n4-vayE9ptCkjq2pT49LtsxbtcDr-6Vd7hGP43_WFaM/edit?usp=sharing

yasuohayashibara, 2021-02-05:
切削油には以下を使用している．
Hysol SL 36 XBB

yasuohayashibara, 2021-02-05:
本日GFRP切削のため高さ方向のずれを調べたところ，およそ0.08程度ずれていることが判明

yasuohayashibara, 2021-02-12:
切削が順調に進んでいるため，ほぼマニュアルが完成したと思いますので，issueを閉じます．

yasuohayashibara, 2021-02-19:
アルミ(A2017S)の切削の様子
https://youtu.be/SpFrFi8tTu4

Closed 2021-02-12.

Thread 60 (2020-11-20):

Autodesk Inventor CAM 2020を用いたGankenKun切削パスの生成法

yasuohayashibara, 2020-11-20:
Autodesk Inventor CAM 2020を用いたGankenKun切削パスの生成法に関して示す．

yasuohayashibara, 2020-11-20:
以下に示した．

https://docs.google.com/document/d/1MHM7T2BDNjA8xqrB54MIc1QrvLaiD6PXMtrIb-hadEg/edit?usp=sharing

yasuohayashibara, 2021-02-12:
生成の手順を示して現在切削しているためissueを閉じます．

Closed 2021-02-12.

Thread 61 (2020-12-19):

足裏のGFRPの素材

yasuohayashibara, 2020-12-19:
足裏のGFRPの素材が分からなくなったので，こちらに記載しておく．
これも含めて材料のリストをどこかに示したほうが良い．

https://store.shopping.yahoo.co.jp/robotena/m0145.html?pid=ibx&bid=1&sc_e=mshp_nc_con_77_pc_NC00034308

yasuohayashibara, 2020-12-19:
issueを閉じます．

Closed 2020-12-19.

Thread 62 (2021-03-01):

電子部品リストの作成

yasuohayashibara, 2021-03-01:
電子部品のリストを作成する．

yasuohayashibara, 2021-03-01:
- 電圧計
超小型２線式ＬＥＤデジタル電圧計（パネルメータ）３桁表示　ＤＣ３～１５Ｖ（赤色）オートレンジ
通販コード　M-08468
https://akizukidenshi.com/catalog/g/gM-08468/

yasuohayashibara, 2021-03-01:
・DC-DCコンバータ
Aideepen 5個セット DC-DC 1.25-36V 4A XL6009オートブーストバックモジュール調整可能MOSFETスイッチステップアップステップダウンコンバータボード
https://www.amazon.co.jp/gp/product/B07S8WTHHF/ref=ppx_yo_dt_b_search_asin_title?ie=UTF8&psc=1

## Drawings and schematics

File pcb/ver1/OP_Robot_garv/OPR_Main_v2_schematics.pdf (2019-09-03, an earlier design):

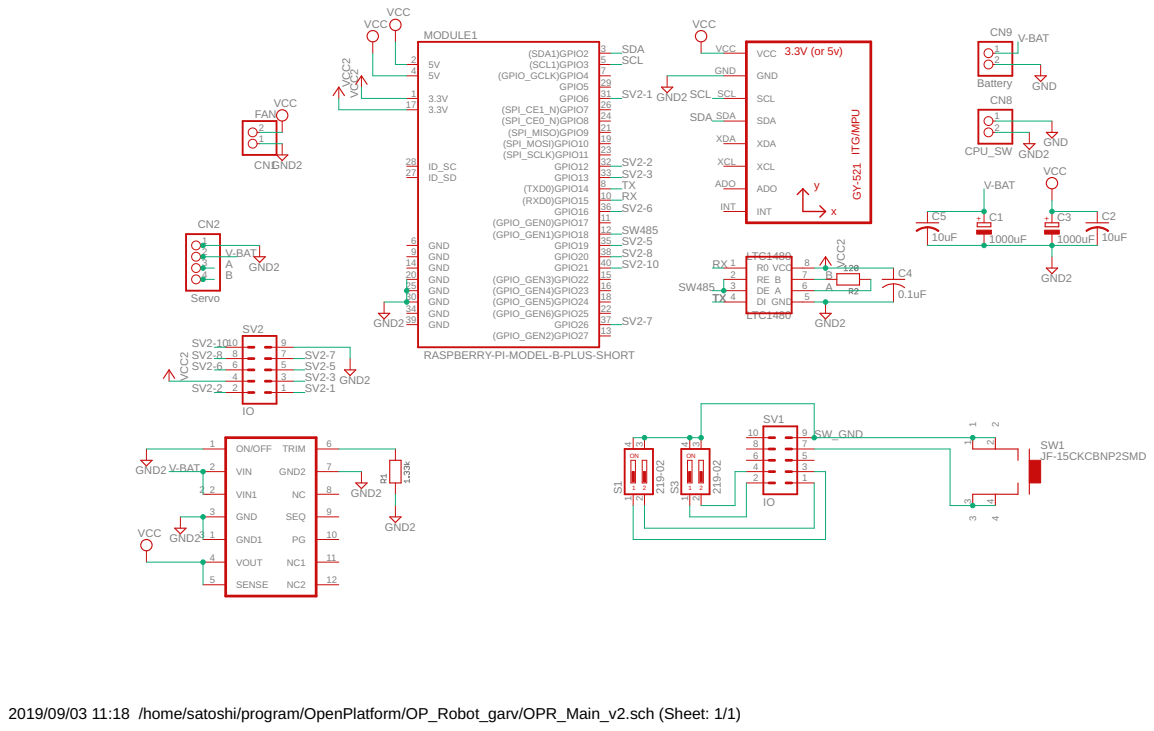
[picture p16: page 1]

RASPBERRY-PI-MODEL-B-PLUS-SHORT

2019/09/03 11:18 /home/satoshi/program/OpenPlatform/OP_Robot_garv/OPR_Main_v2.sch (Sheet: 1/1)

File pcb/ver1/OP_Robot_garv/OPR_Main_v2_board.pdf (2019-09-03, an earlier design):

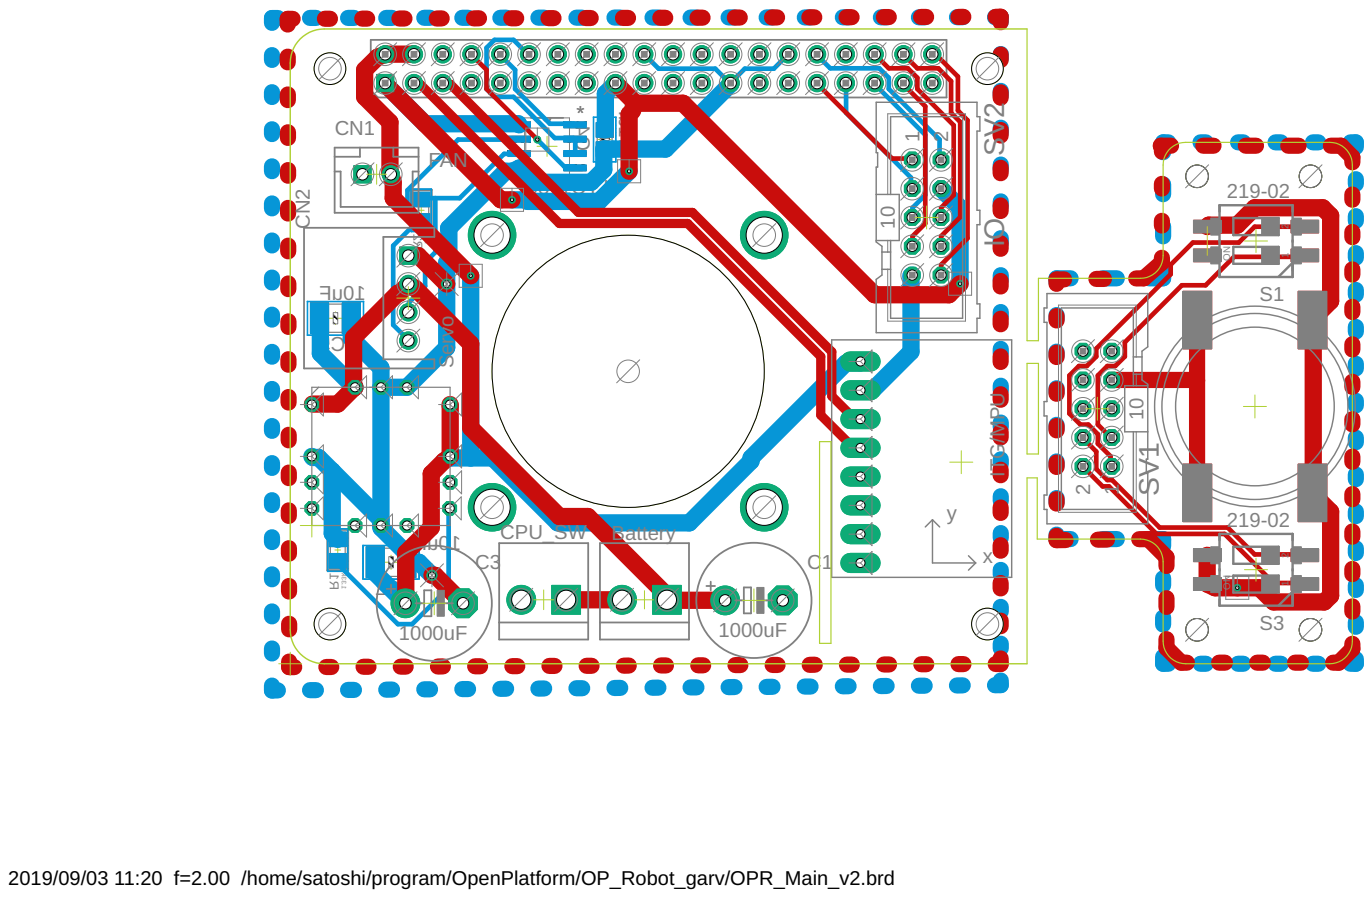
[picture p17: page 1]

2019/09/03 11:20 f=2.00 /home/satoshi/program/OpenPlatform/OP_Robot_garv/OPR_Main_v2.brd

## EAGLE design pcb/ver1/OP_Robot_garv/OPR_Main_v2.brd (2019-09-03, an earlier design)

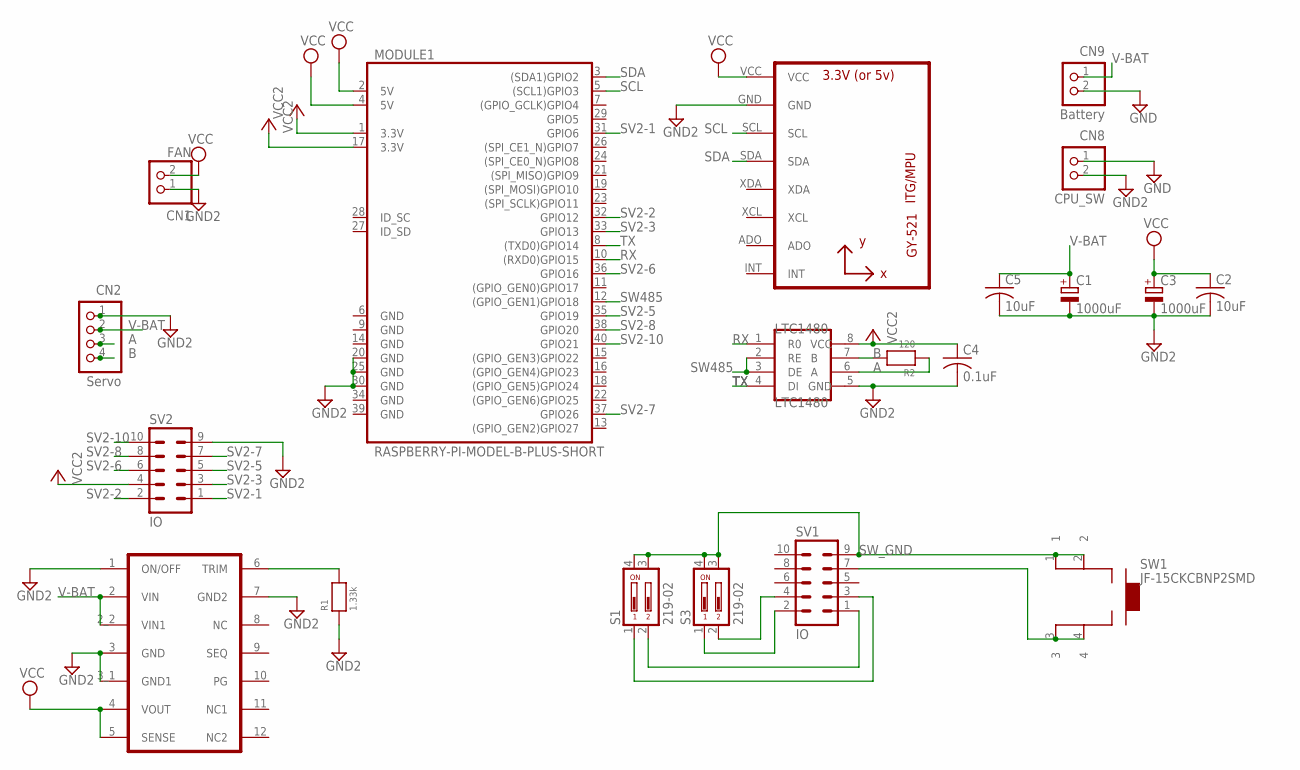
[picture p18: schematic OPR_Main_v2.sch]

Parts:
C1, C3: 1000uF; E5-10,5
C2, C5: 10uF; C3225
C4: 0.1uF; C2012
CN1: FAN; B2B-XH-A
CN2: Servo; S4B-XH-A
CN8: CPU_SW; B2P-VH
CN9: Battery; B2P-VH
LTC1480: LTC1480; SOIC-8
MODULE1: RASPBERRY-PI-MODEL-B-PLUS-SHORT
R1: 1.33k; 0805_NOTHERMALS
R2: 120; 0805_NOTHERMALS
S1, S3: 219-02; CTS-219-02
SV1, SV2: IO; ML10
SW1: JF-15CKCBNP2SMD; JF-15CKCBNP2-SMD
U1: GY-521MPU6050; GY-521
U$3: OKL-T/W-12N-C; OKL_T6_W12

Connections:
A: CN2.3, LTC1480.6 (A), R2.1
B: CN2.4, LTC1480.7 (B), R2.2
GND: CN8.1, CN9.2
GND2: C1.-, C2.2, C3.-, C4.2, C5.2, CN1.1, CN2.1, CN8.2, LTC1480.5 (GND), MODULE1.20 (GND), MODULE1.25 (GND), MODULE1.30 (GND), R1.1, SV2.9, U1.GND, U$3.1 (ON/OFF), U$3.3 (GND), U$3.3_1 (GND1), U$3.7 (GND2)
unnamed: R1.2, U$3.6 (TRIM)
unnamed: S3.2, SV1.4
unnamed: SV1.7, SW1.3, SW1.4
unnamed: S3.1, SV1.2
unnamed: S1.2, SV1.1
unnamed: S1.1, SV1.3
RX: LTC1480.1 (R0), MODULE1.10 ((RXD0)GPIO15)
SCL: MODULE1.5 ((SCL1)GPIO3), U1.SCL
SDA: MODULE1.3 ((SDA1)GPIO2), U1.SDA
SV2-1: MODULE1.31 (GPIO6), SV2.1
SV2-2: MODULE1.32 (GPIO12), SV2.2
SV2-3: MODULE1.33 (GPIO13), SV2.3
SV2-5: MODULE1.35 (GPIO19), SV2.5
SV2-6: MODULE1.36 (GPIO16), SV2.6
SV2-7: MODULE1.37 (GPIO26), SV2.7
SV2-8: MODULE1.38 (GPIO20), SV2.8
SV2-10: MODULE1.40 (GPIO21), SV2.10
SW485: LTC1480.2 (RE), LTC1480.3 (DE), MODULE1.12 ((GPIO_GEN1)GPIO18)
SW_GND: S1.3, S1.4, S3.3, S3.4, SV1.9, SW1.1, SW1.2
TX: LTC1480.4 (DI), MODULE1.8 ((TXD0)GPIO14)
V-BAT: C1.+, C5.1, CN2.2, CN9.1, U$3.2 (VIN), U$3.2_2 (VIN1)
VCC: C2.1, C3.+, CN1.2, MODULE1.2 (5V), MODULE1.4 (5V), U1.VCC, U$3.4 (VOUT), U$3.5 (SENSE)
VCC2: C4.1, LTC1480.8 (VCC), MODULE1.1 (3.3V), MODULE1.17 (3.3V), SV2.4

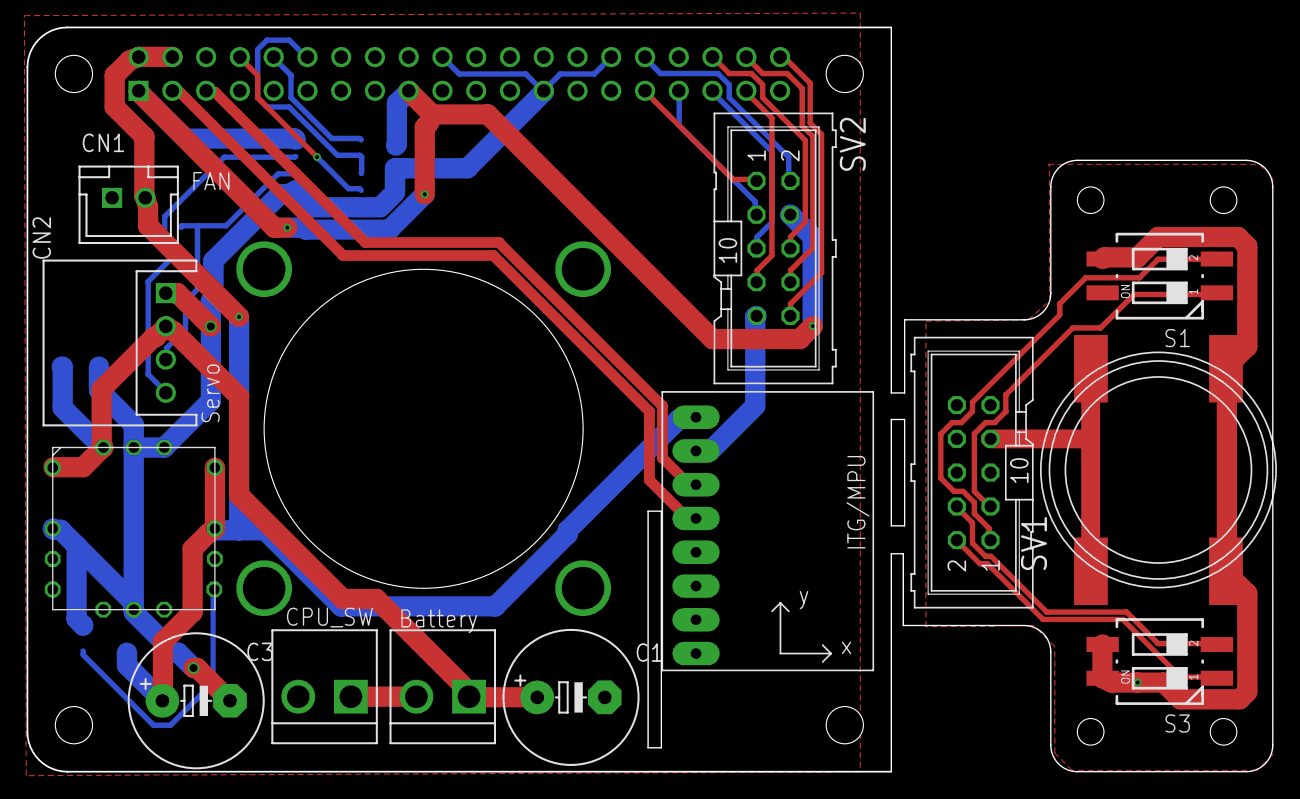
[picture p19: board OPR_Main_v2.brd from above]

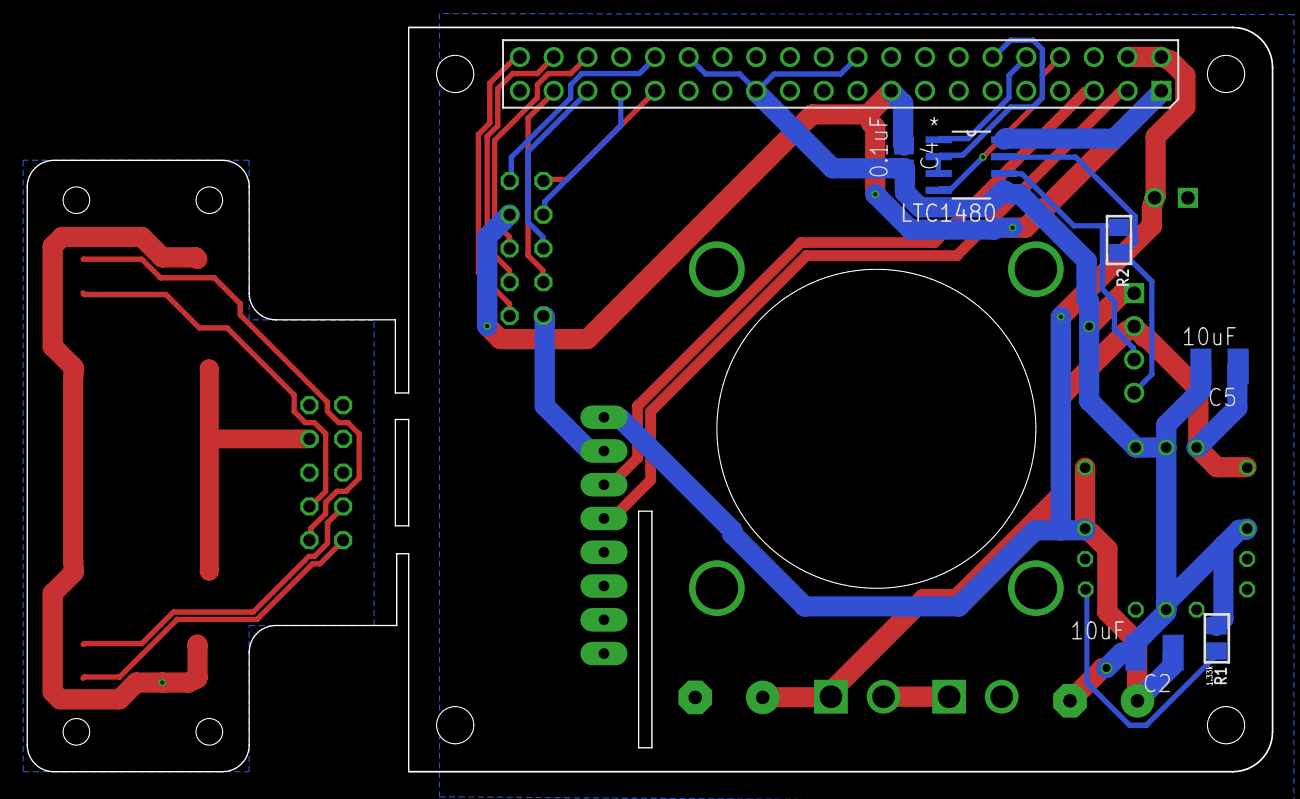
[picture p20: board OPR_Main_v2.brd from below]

Board: 2 copper layers, 93.7 x 56.0 mm, 20 parts (6 on the bottom side), 27 nets.

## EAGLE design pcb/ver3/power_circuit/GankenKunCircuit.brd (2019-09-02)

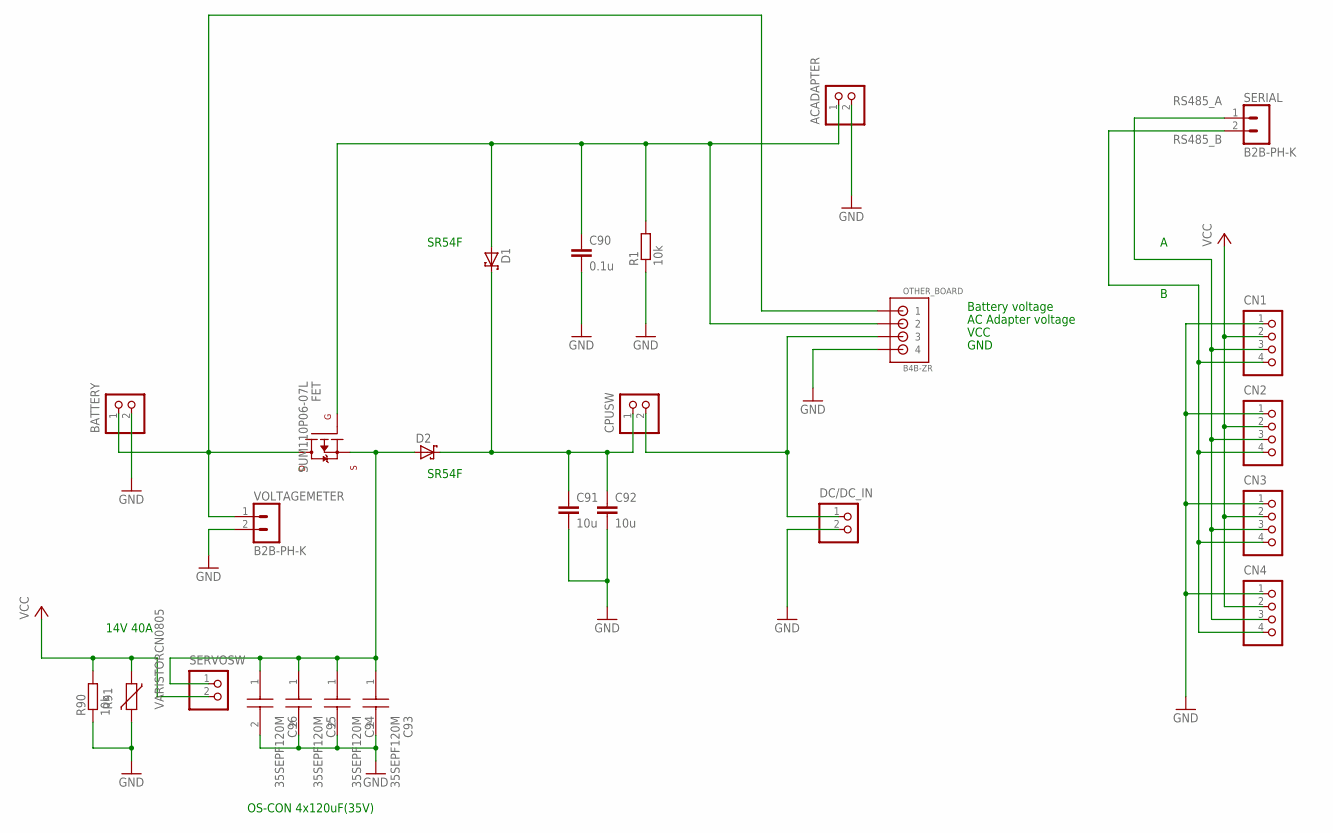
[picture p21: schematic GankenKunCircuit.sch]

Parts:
ACADAPTER: B2B-XH-A
BATTERY: B2P-VH
C90: 0.1u; C1608
C91, C92: 10u; C3216
C93, C94, C95, C96: 35SEPF120M; CAPPRD500W65D1000H1350
CN1, CN2, CN3, CN4: B4B-XH-A
CPUSW: B2B-XH-A
D1, D2: SCHOTTKY-DIODESMD; SMB
DC/DC_IN: B2B-XH-A
FET: SUM110P06-07L; TO-263-2
OTHER_BOARD: B4B-ZR
R1, R90: 10k; R0603
R91: VARISTORCN0805; CT/CN0805
SERIAL: B2B-PH-K
SERVOSW: B2P-VH
VOLTAGEMETER: B2B-PH-K

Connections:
GND: ACADAPTER.2, BATTERY.2, C90.2, C91.2, C92.2, C93.2 (-), C94.2 (-), C95.2 (-), C96.2 (-), CN1.1, CN2.1, CN3.1, CN4.1, DC/DC_IN.2, OTHER_BOARD.4, R1.1, R90.1, R91.2, VOLTAGEMETER.2
unnamed: BATTERY.1, FET.4 (D), OTHER_BOARD.1, VOLTAGEMETER.1
unnamed: C93.1 (+), C94.1 (+), C95.1 (+), C96.1 (+), D2.A, FET.3 (S), SERVOSW.1
unnamed: C91.1, C92.1, CPUSW.1, D1.C, D2.C
unnamed: ACADAPTER.1, C90.1, D1.A, FET.1 (G), OTHER_BOARD.2, R1.2
unnamed: CPUSW.2, DC/DC_IN.1, OTHER_BOARD.3
RS485_A: CN1.3, CN2.3, CN3.3, CN4.3, SERIAL.1
RS485_B: CN1.4, CN2.4, CN3.4, CN4.4, SERIAL.2
VCC: CN1.2, CN2.2, CN3.2, CN4.2, R90.2, R91.1, SERVOSW.2

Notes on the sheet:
14V 40A
SR54F
OS-CON 4x120uF(35V)
Battery voltage
AC Adapter voltage
VCC
GND

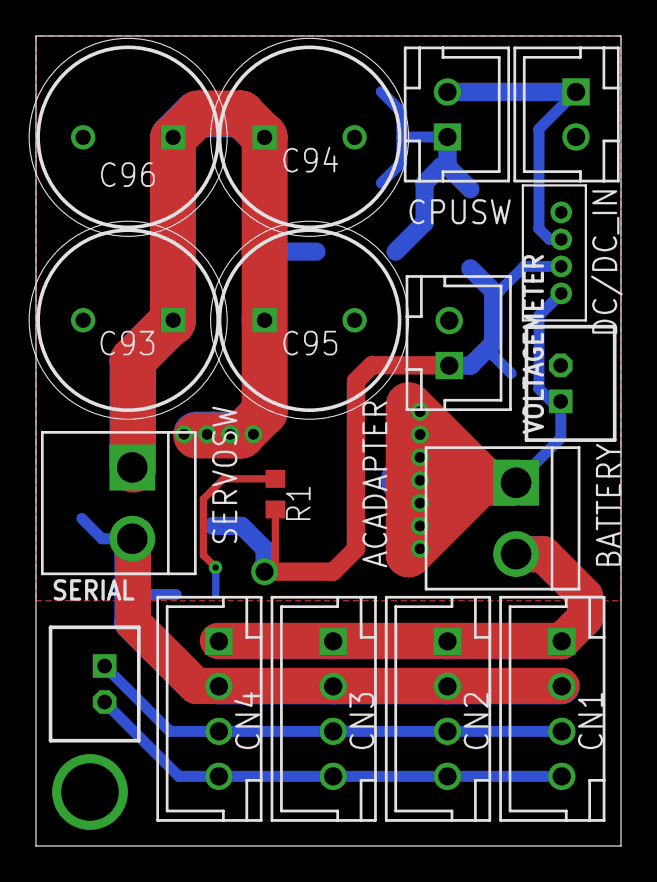
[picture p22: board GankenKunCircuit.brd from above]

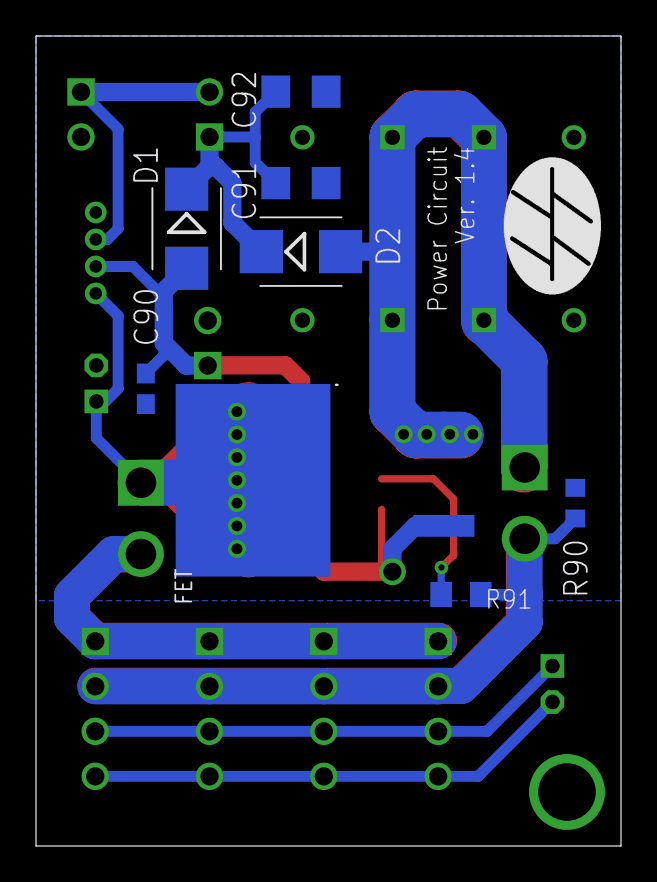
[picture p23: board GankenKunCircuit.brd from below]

Board: 2 copper layers, 32.5 x 45.0 mm, 25 parts (8 on the bottom side), 9 nets.

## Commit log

2016-12-30 Inventor2016 CAD files
    [AETTF8-135-M3-N3.ipt, ALSFB6-66.ipt, AMP-340E.ipt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]
2017-08-26 Add V-Rep simulation model file
    [AETTF8-135-M3-N3.0003.ipt, AETTF8-135-M3-N3.ipt, ALSFB6-66.ipt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]
2018-10-14 Added OpenPlatform_ver3_0
    [AETTF8-135-M3-N3.ipt, ALSFB6-66.ipt, AMP-340E.ipt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]
2018-10-14 Added stl file
2018-10-22 Fixed Head
    [カメラ_外装.ipt, 上半身.iam, 本体.iam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]
2018-10-23 Added spimplified model
    [AnkleL.ipt, AnkleR.ipt, FootL.ipt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]
2018-10-25 Added アンテナパーツ_MIR
    [アンテナパーツ.ipt, アンテナパーツ_MIR.ipt, コックピット_2.iam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]
2018-10-29 Minor fixes
    [KBCR-S02MU.ipt, New_Accelite_Controller_Cover.ipt, カメラ_外装.ipt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]
2018-11-01 Fix link relationship
    [リンク_6_1.iam, リンク_6_3.iam, リンク_メインフレーム_6_1.ipt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]
2018-11-05 Fix miss
    [F694ZZ Ball.ipt, F694ZZ Inner Ring.ipt, F694ZZ Outer Ring.ipt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]
2019-03-24 Add parts status
    [ARU-305_5.ipt, ASU-340.ipt, B3M10xx.ipt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]
2019-03-24 Fix arms
    [上半身.iam, 上腕_1.iam, 上腕_サブフレーム_1_1.ipt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]
2019-05-14 Add torso subframe 1_4_MIR #47
    [上半身.iam, 本体.iam, 胴体_1.iam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]
2019-06-16 foot for RoboCup2019
    [足裏_メインフレーム_2_3.ipt]
2019-06-16 assemble about foot
    [下半身_6.iam, 足裏_1_1.iam, 足裏_1_1_MIR.iam]
2019-06-23 Cockpit camera cable wiring
    [コックピット_2.iam, コックピット_2_メインフレーム_1.ipt, コックピット_2_メインフレーム_1_MIR.ipt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]
2019-09-02 add power circuit board and schematics data
    [GankenKunCircuit.brd, GankenKunCircuit.sch]
2019-09-03 update pcb data
    [GankenKunCircuit.brd, GankenKunCircuit.sch, OPR_Main_v2.brd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]
2019-09-03 add readme for pcb data
2019-09-13 Change batterybox
    [New_Accelite_Controller_Cover_copy.ipt, New_Accelite_Controller_Cover_copy_under.ipt, コックピット_サブフレーム_1_5.ipt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]
2019-09-13 Antenna change
    [Antenna.ipt, Antenna_MIR.ipt, コックピット_2.iam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]
2019-09-13 Add camera cable assist
    [CameraCable_Assist.ipt, 上半身.iam, 本体.iam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]
2019-09-13 Add TPU bumpers
    [FreundBumper_Stand.ipt, FreundBumper_Stand_MIR.ipt, FrontBumper.iam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]
2019-09-13 Fix parameters
    [CIT_OP_J120_Mount.ipt, 上半身.iam, 本体.iam]
2019-09-13 Fix parameter of 足裏_メインフレーム_2_3
    [足裏_メインフレーム_2_3.ipt]
2020-10-14 Camera 3D printed parts compatible with L-shaped USB cable
    [カメラ_外装.ipt]
2020-11-14 add mente_stand
    メンテナンス台のモデルを追加しました
    [Maintenance_stand.iam, menteA.ipt, menteB.ipt]

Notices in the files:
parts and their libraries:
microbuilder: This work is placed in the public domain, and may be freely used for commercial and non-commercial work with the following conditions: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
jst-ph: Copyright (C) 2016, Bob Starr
